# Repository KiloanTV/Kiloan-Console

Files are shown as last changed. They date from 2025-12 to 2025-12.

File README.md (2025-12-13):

<div>
  <h1 align="center">Kiloan Desk</h1>

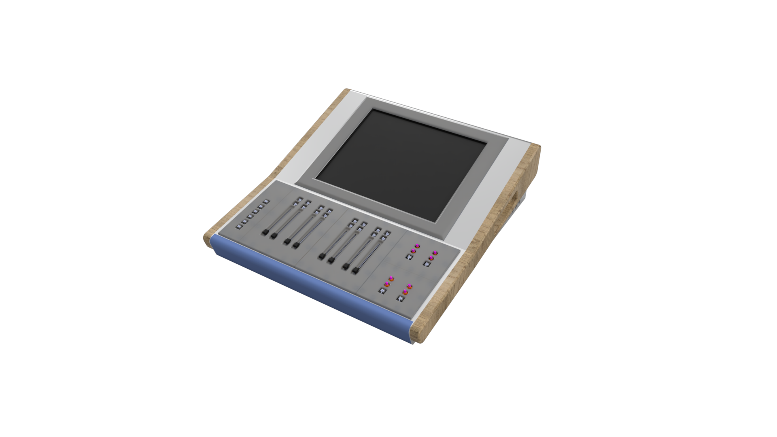
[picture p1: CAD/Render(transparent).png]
Kiloan-Desk
  

  <p align="center">
  <a href="https://blueprint.hackclub.com/">
    
  </a>
  </p>
  <h1></h1>
  <p align="center">
    A customizable mixing console like high quality chassis system for building your own console systems.
  </p>
</div>

<sub align="center">This work is licensed under the
[MIT License](https://mit-license.org).
</sub>

## Table of Contents

- [About](#about)
- [Pictures](#pictures)
- [Bill of Materials](#bill-of-materials)

# About

I have a dream: a self-designed system where everyone can build the perfect mixing console/video console/DIY whatever console out of Aluminum Sheet Metal and a bit of the best hoppyist in house fabrication, 3d printing! And that's why I did this project, it's adapted somewhat to my current wishes and needs, but it can be individually adapted and replicated by anyone without breaking the budget.

# Pictures

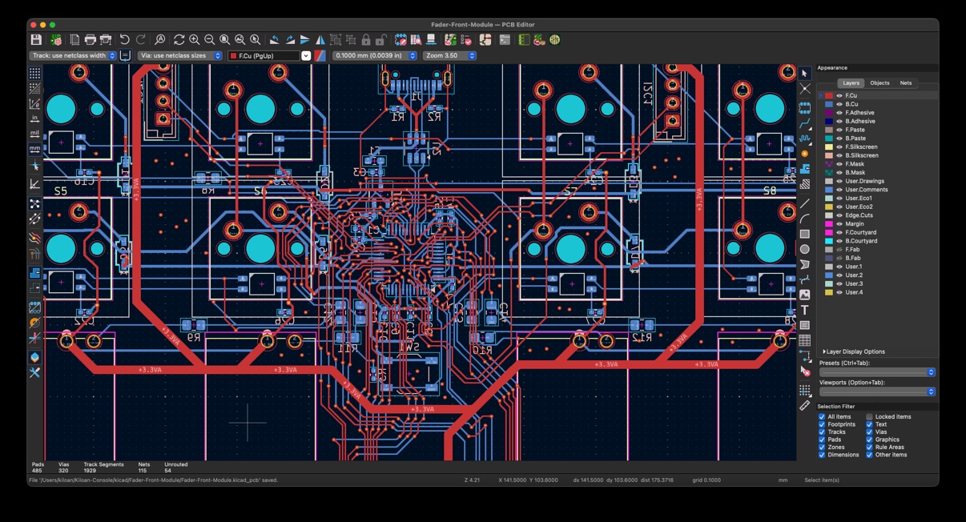
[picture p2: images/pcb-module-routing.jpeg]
pcb-routing


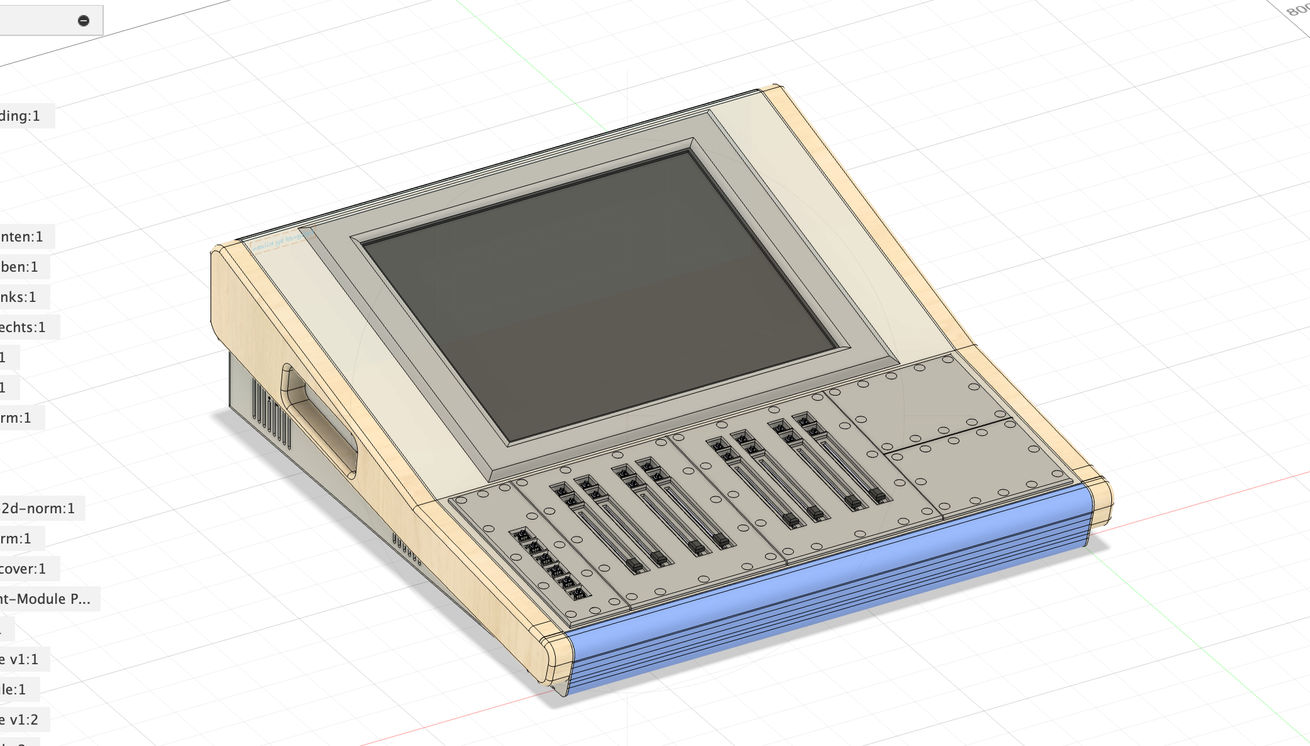
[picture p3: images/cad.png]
cad


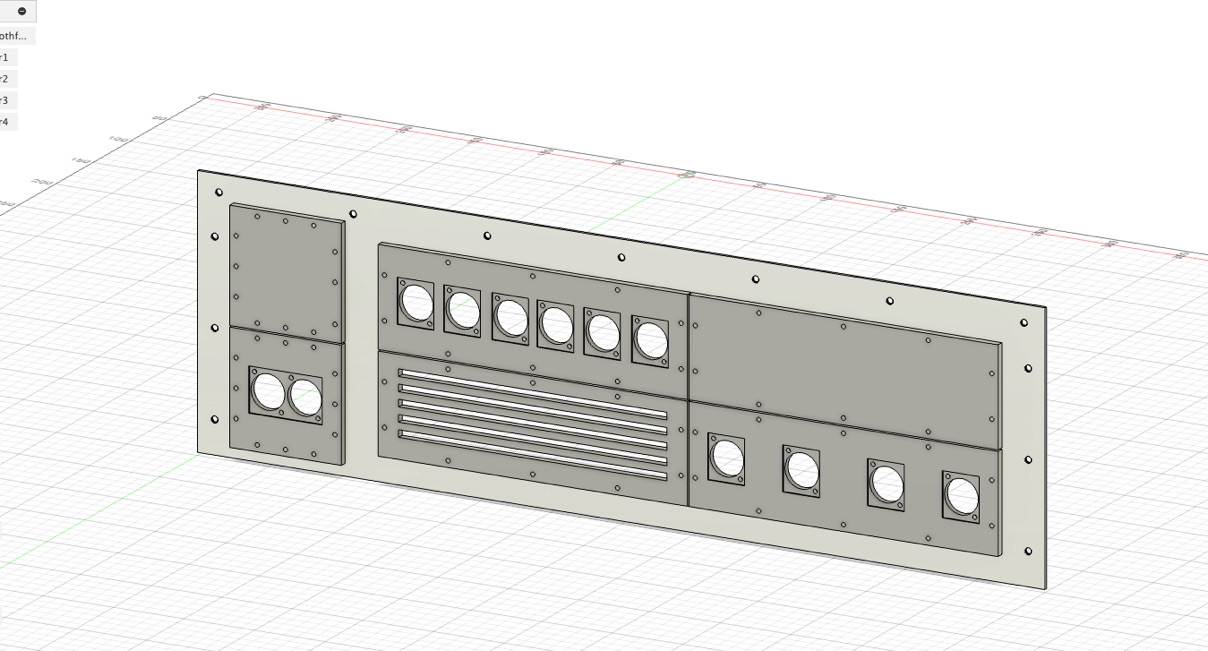
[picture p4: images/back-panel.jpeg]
backpanel


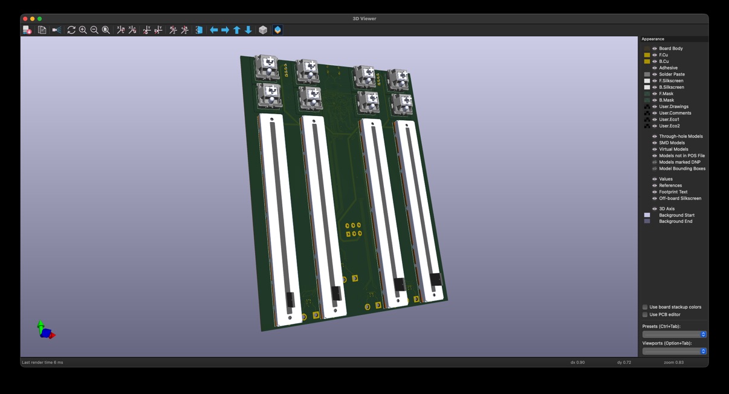
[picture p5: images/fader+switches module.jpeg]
pcb


# Bill of Materials

<details>
<summary><strong>Show Bill Of Materials(BOM) ----></strong></summary>

|Part Name |Quantity |Price |Vendor |Shipping Cost |Total Cost |Link(if applicable) |
|---|---|---|---|---|---|---|
|Misc Front Module PCBs + Stencil |1x5 |€9.35 |jlcpcb | | | |
|Fader Front Module PCBs + Stencil |1x5 |€16.58 |jlcpcb | | | |
|Deck Switcher Front Module PCBs + Stencil |1x5 |€10.71 |jlcpcb |Shipping for all 3 PCB orders: €47.18 | | |
|LCSC Electronic Components for 1x Deck Switcher/2x Fader/2x Misc|1 Order for everything(see lcsc cart export)|€87,81 |lcsc |€9,37 | | |
|Keyswitches for the PCBs |3x10pcs |€5,20 |aliexpress |€0 | |https://de.aliexpress.com/item/1005006814061416.html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|
|M5x10mm Screws |3x100pcs |€7,08 |schraubenking-shop.de(local and cheapest in my country)| | |https://www.schraubenking-shop.de/M5-x-10mm-Linsenkopfschrauben-TX-ISO14583-Edelstahl-A2-P004399 |
|M3x10mm Screws |1x100pcs |€1,98 |schraubenking-shop.de(local and cheapest in my country)|Shipping for everything from schraubenking: €5,84| |https://www.schraubenking-shop.de/M3-x-10mm-Linsenkopfschrauben-TX-ISO14583-Edelstahl-A2-P004381 |
|JLCCNC Sheet Metal Parts |10 individual parts |€146.97 |jlccnc |€78.28 | |jlccnc.com |
|Estimated Total | |€285,68 ($335,30)| |€140.67 ($165,15) |€426,35 ($500,56)| |

</details>

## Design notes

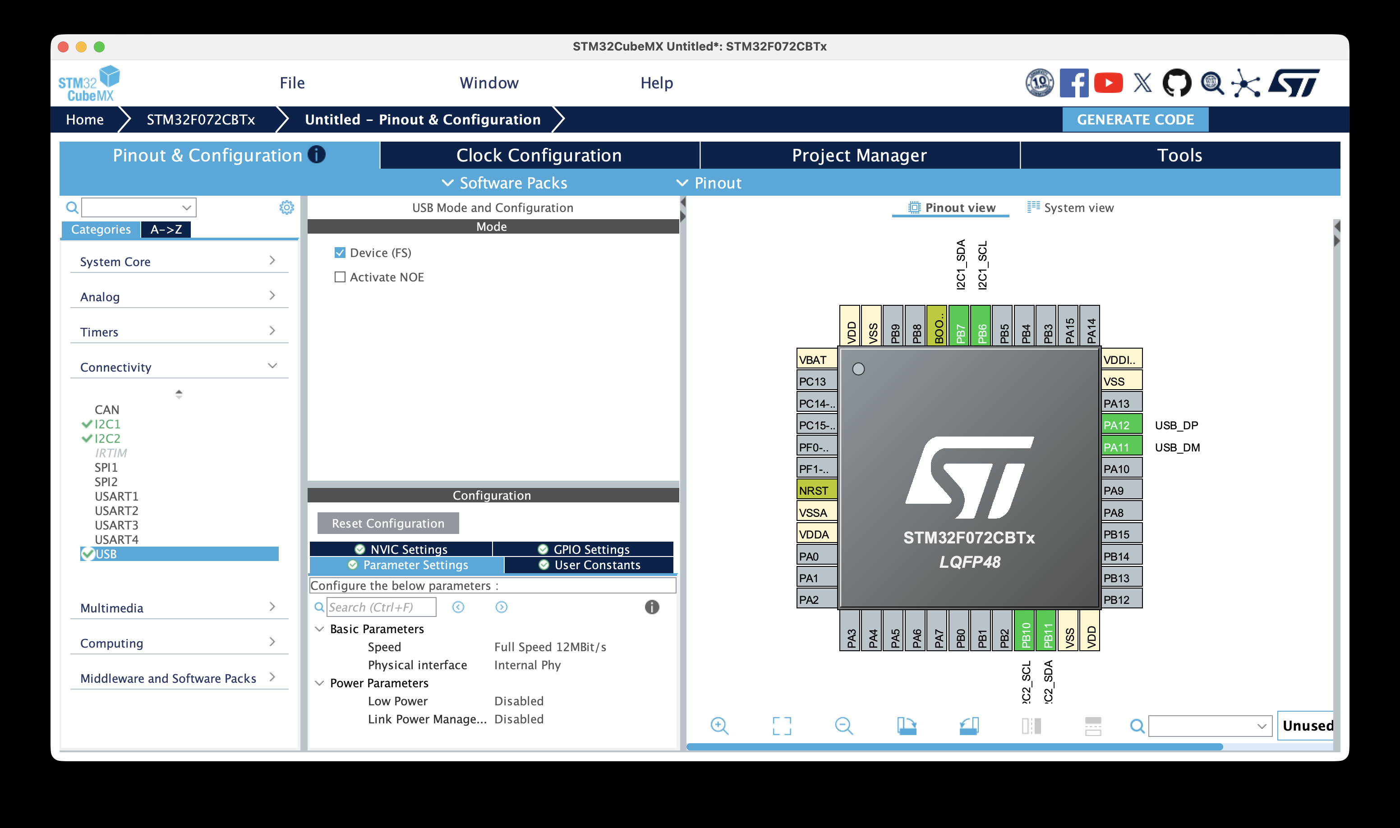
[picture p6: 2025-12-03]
firmware/General Pinout.png

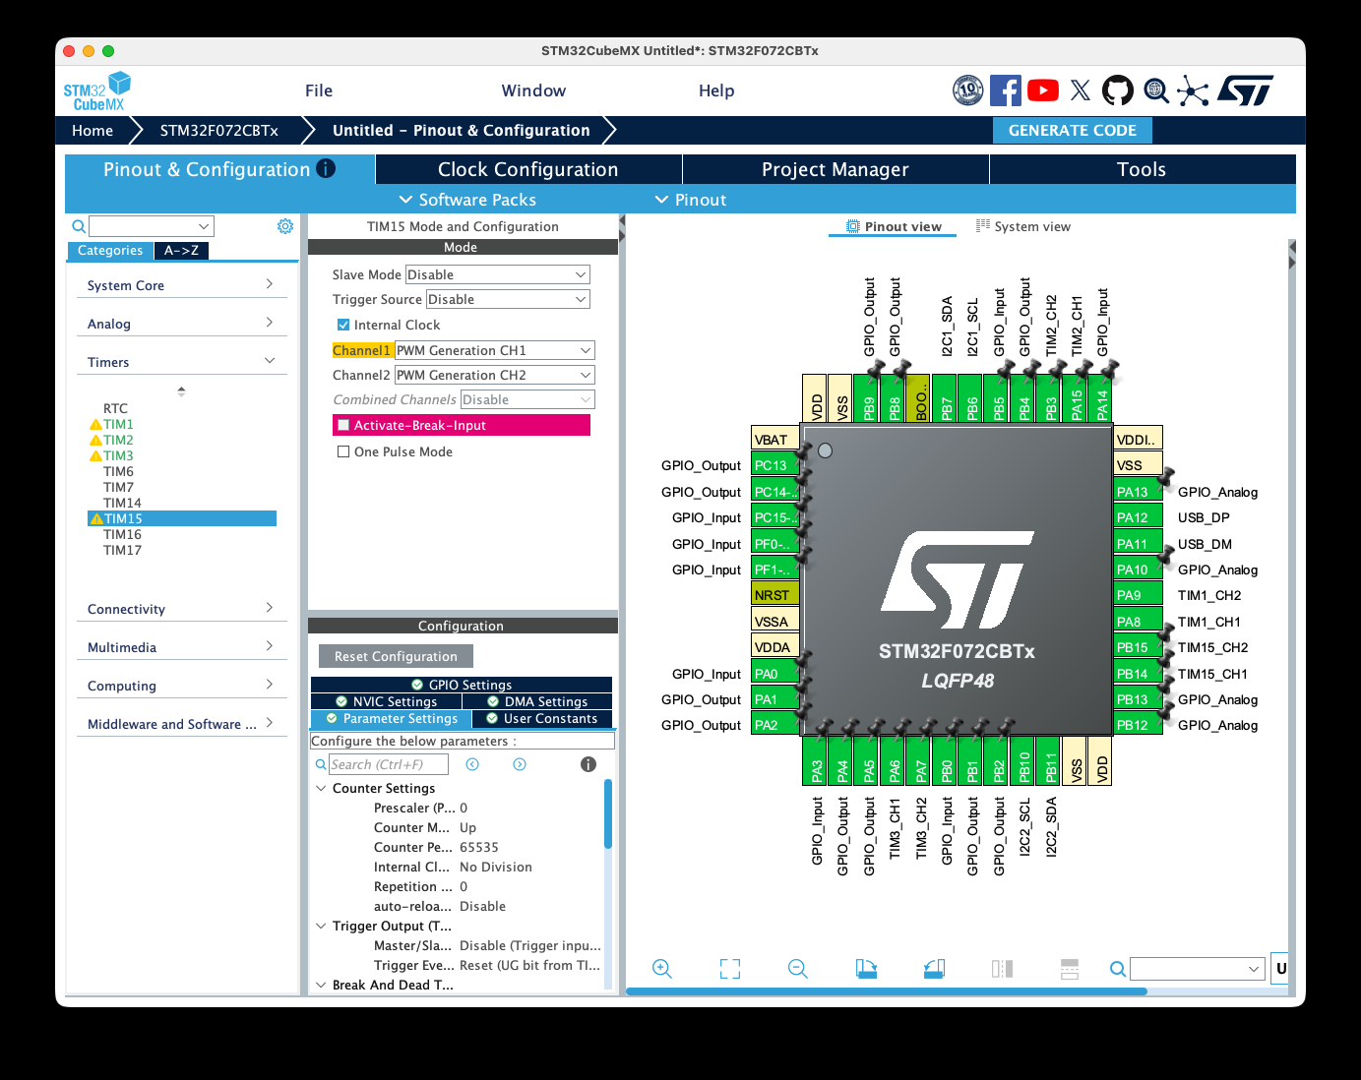
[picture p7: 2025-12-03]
firmware/Fader Module Pinout.png

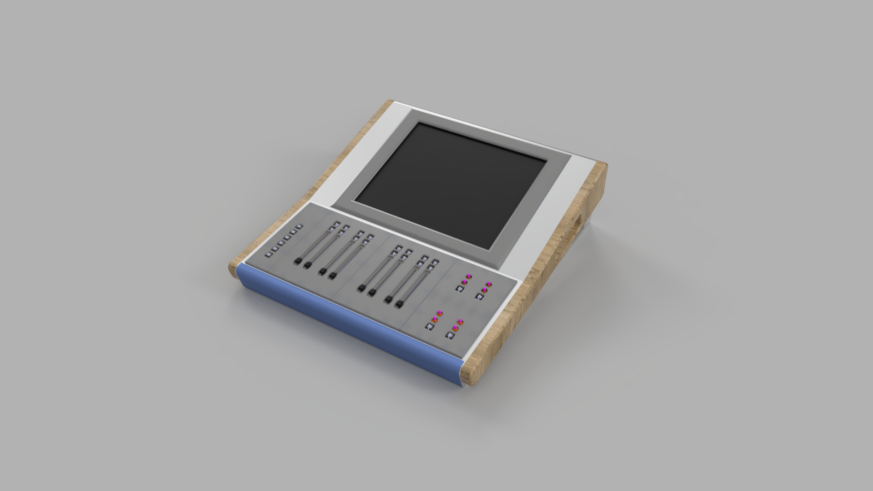
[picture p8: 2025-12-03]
CAD/Render.png

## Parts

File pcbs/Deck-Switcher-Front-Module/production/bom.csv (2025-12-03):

Designator | Footprint | Quantity | Value | LCSC Part #
C1, C11, C12, C13, C14, C15, C16, C17, C2, C5, C9 | 0402 | 11 | 100nF | C307331
C10, C6 | 0402 | 2 | 4.7uF | C23733
C3, C4, C8 | 0402 | 3 | 1uF | C52923
C7 | 0402 | 1 | 10nF | C15195
D1, D2, D3, D4, D5, D6 | SOD-123_ONS | 6 | Diode | C11177
F1 | 0603 | 1 | 500mA | C210357
J1 | USB_C_Receptacle_HRO_TYPE-C-31-M-12 | 1 | USB_C | C165948
J2, J3 | JST_EH_B4B-EH-A_1x04_P2.50mm_Vertical | 2 | I2C1 | C160258
J4 | SolderWire-2sqmm_1x02_P7.8mm_D2mm_OD3.9mm | 1 | External PowerSupply | C471417
LED1, LED2, LED3, LED4, LED5, LED6 | LED_SK6812MINI | 6 | LED_SK6812MINI | C5149201
R1, R2, R41, R42, R43, R44 | 0402 | 6 | 5.1k | C25905
R3 | 0402 | 1 | 10k | C25744
R4 | 0805 | 1 | 500Ω | C2828857
S1, S2, S3, S4, S5, S6 | MX_PCB_1.00u | 6 | Keyswitch
SW1 | SW_SPST_TL3342 | 1 | SW_Push | C115351
U1 | SOT-23-3 | 1 | XC6206 | C5446
U2 | SOT-23-6_Handsoldering | 1 | USBLC6-2SC6 | C2827654
U3 | LQFP-48_7x7mm_P0.5mm | 1 | STM32F072CBT6 | C81720

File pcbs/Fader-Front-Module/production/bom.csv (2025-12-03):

Designator | Footprint | Quantity | Value | LCSC Part #
C1, C11, C16, C2, C22, C23, C24, C25, C26, C27, C28, C5, C9 | 0402 | 13 | 100nF | C307331
C10, C6 | 0402 | 2 | 4.7uF | C23733
C12, C13, C14, C15 | 0805 | 4 | 1nF | C94121
C17, C21, C29, C30, C34, C35, C39, C40 | 0805 | 8 | 10uF | C15850
C18, C31, C36, C41 | 0805 | 4 | 1uF | C28323
C19, C32, C37, C42 | 0805 | 4 | 100nF | C49678
C20, C33, C38, C43 | 0805 | 4 | 10nF | C1710
C3, C4, C8 | 0402 | 3 | 1uF | C52923
C7 | 0402 | 1 | 10nF | C15195
D1, D2, D3, D4, D5, D6, D7, D8 | SOD-123_ONS | 8 | Diode | C11177
D10, D11, D12, D9 | LL-34 | 4 | Motor Diode | C2891753
F1 | 0603 | 1 | 500mA | C210357
J1 | USB_C_Receptacle_HRO_TYPE-C-31-M-12 | 1 | USB_C | C165948
J10, J12, J6, J8 | SolderWire-2sqmm_1x02_P7.8mm_D2mm_OD3.9mm | 4 | motor_port_1
J11, J5, J7, J9 | TRANS_TSM018NB03CR_RLG | 4 | MOSFET P-CH 40V 70A PDFN5x6-8L | C5297498
J2, J3 | JST_EH_B4B-EH-A_1x04_P2.50mm_Vertical | 2 | I2C1 | C160258
J4 | Molex_Mini-Fit_Jr_5566-06A_2x03_P4.20mm_Vertical | 1 | External PowerSupply | C471417
LED1, LED2, LED3, LED4, LED5, LED6, LED7, LED8 | LED_SK6812MINI | 8 | LED_SK6812MINI | C5149201
R1, R2, R41, R42, R43, R44 | 0402 | 6 | 5.1k | C25905
R10, R11, R12, R8, R9 | 0805 | 5 | 500Ω | C2828857
R13, R18, R20, R25, R27, R32, R34, R39 | 0805 | 8 | 22kΩ | C2907243
R14, R21, R28, R35 | 0805 | 4 | 1kΩ | C95781
R15, R16, R17, R19, R22, R23, R24, R26, R29, R30, R31, R33, R36, R37, R38, R40 | 0805 | 16 | 0Ω | DNP
R3 | 0402 | 1 | 10k | C25744
R4, R5, R6, R7 | schieberegler-PTB0153-2010BPB103 | 4 | PTB0153-2010BPB103 | C17427549
S1, S2, S3, S4, S5, S6, S7, S8 | MX_PCB_1.00u | 8 | Keyswitch
SW1 | SW_SPST_TL3342 | 1 | SW_Push | C115351
U1 | SOT-23-3 | 1 | XC6206 | C5446
U2 | SOT-23-6_Handsoldering | 1 | USBLC6-2SC6 | C2827654
U3 | LQFP-48_7x7mm_P0.5mm | 1 | STM32F072CBT6 | C81720
U4, U5, U6, U7 | RXY0014A-MFG | 4 | DRV8243HQRXYRQ1 | C3040833

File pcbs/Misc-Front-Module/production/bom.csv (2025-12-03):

Designator | Footprint | Quantity | Value | LCSC Part #
C1, C11, C12, C13, C14, C15, C16, C17, C18, C19, C2, C5, C9 | 0402 | 13 | 100nF | C307331
C10, C6 | 0402 | 2 | 4.7uF | C23733
C3, C4, C8 | 0402 | 3 | 1uF | C52923
C7 | 0402 | 1 | 10nF | C15195
D1, D2 | SOD-123_ONS | 2 | Diode | C11177
F1 | 0603 | 1 | 500mA | C210357
J1 | USB_C_Receptacle_HRO_TYPE-C-31-M-12 | 1 | USB_C | C165948
J2, J3 | JST_EH_B4B-EH-A_1x04_P2.50mm_Vertical | 2 | I2C1 | C160258
J4 | SolderWire-2sqmm_1x02_P7.8mm_D2mm_OD3.9mm | 1 | External PowerSupply | C471417
R1, R2, R4, R5, R6, R7 | 0402 | 6 | 5.1k | C25905
R10, R11, R12, R13, R14, R15, R3, R8, R9 | 0402 | 9 | 10k | C25744
S1, S2 | MX_PCB_1.00u | 2 | Keyswitch
SW1 | SW_SPST_TL3342 | 1 | SW_Push | C115351
U1 | SOT-23-3 | 1 | XC6206 | C5446
U2 | SOT-23-6_Handsoldering | 1 | USBLC6-2SC6 | C2827654
U3 | LQFP-48_7x7mm_P0.5mm | 1 | STM32F072CBT6 | C81720
U4, U5, U6, U7 | EC12D1524403 | 4 | encoder EC12D1524403 | C112349

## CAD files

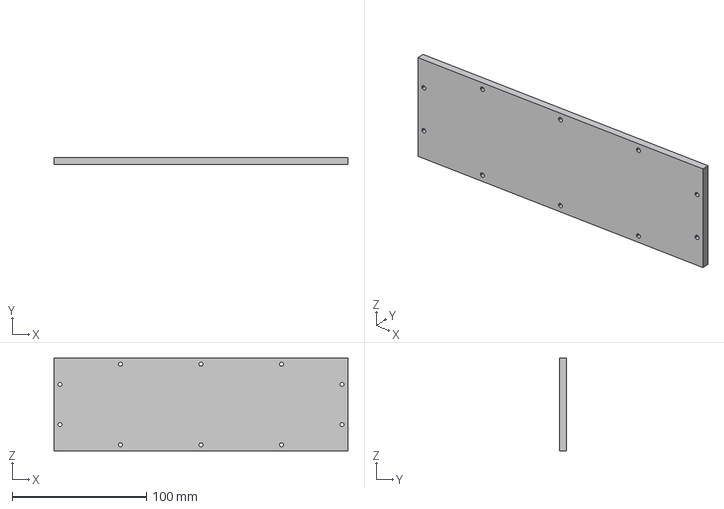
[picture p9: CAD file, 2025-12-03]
CAD/3D Printed/Back Modules/Big.step
219.0 x 5.00 x 69.0 mm

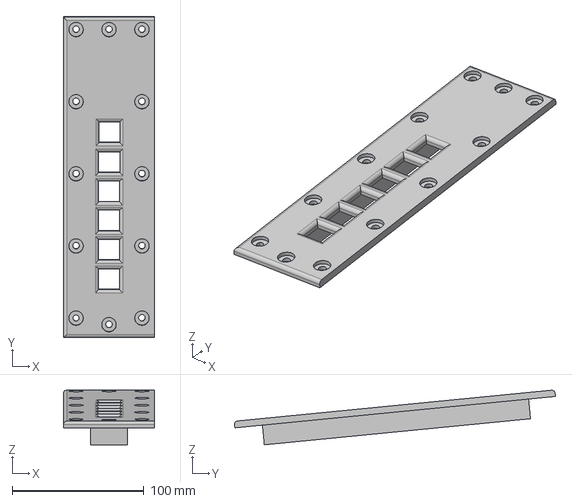
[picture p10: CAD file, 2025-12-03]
CAD/3D Printed/Front Modules/Desk-Switcher/Desk-Switcher-up.step
69.0 x 243.6 x 41.5 mm

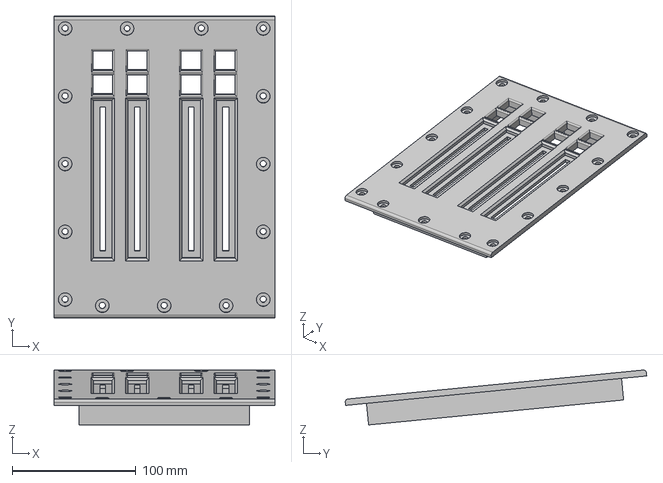
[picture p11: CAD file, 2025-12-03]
CAD/3D Printed/Front Modules/Fader-Module/Fader-Module-up.step
178.5 x 243.6 x 44.3 mm

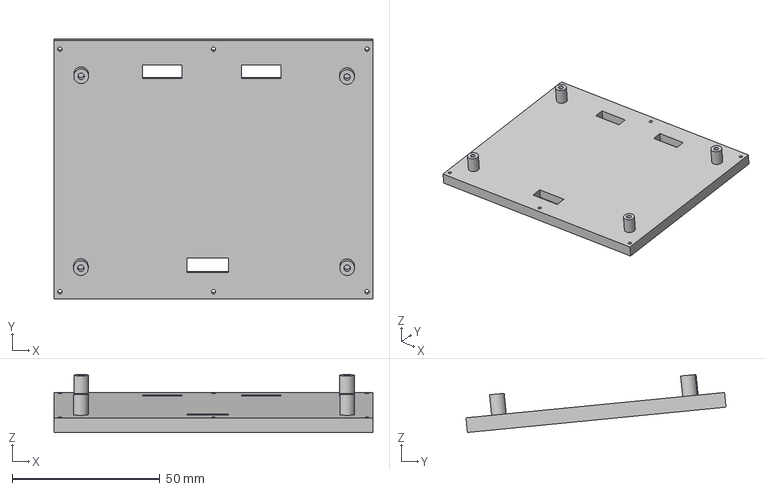
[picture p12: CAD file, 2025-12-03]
CAD/3D Printed/Front Modules/Misc-down/Misc-Down-down.step
108.0 x 88.1 x 19.6 mm

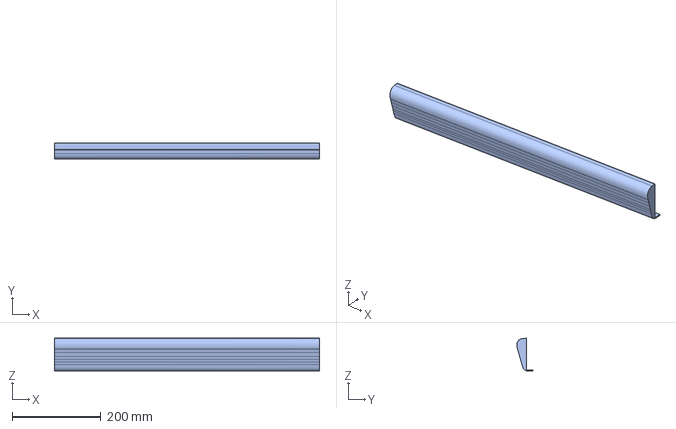
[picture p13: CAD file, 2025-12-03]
CAD/3D Printed/Front-Rounding.step
596.0 x 36.7 x 73.5 mm

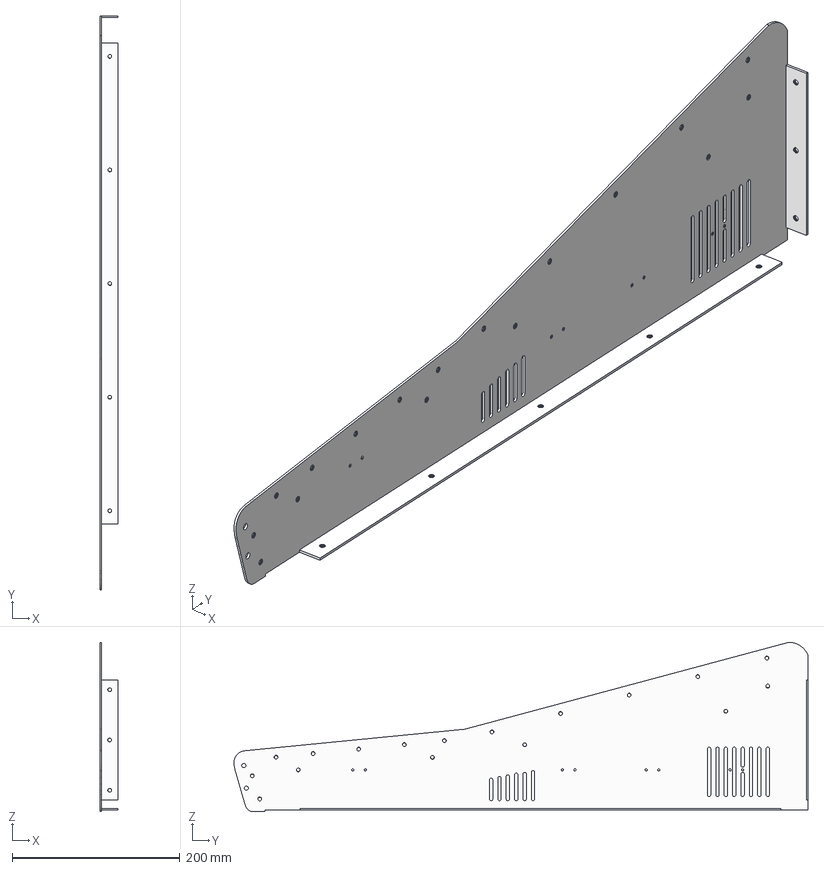
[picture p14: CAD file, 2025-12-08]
CAD/Sheet Metal (2mm Alu)/Left.step
22.0 x 684.7 x 202.0 mm

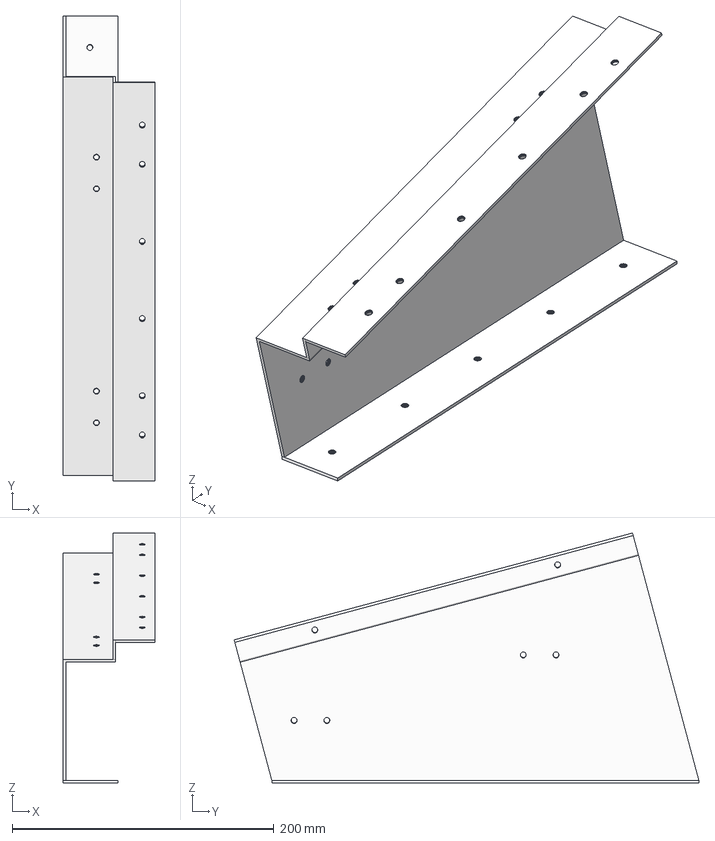
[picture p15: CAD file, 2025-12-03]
CAD/Sheet Metal (2mm Alu)/Screen-Mount/Screen-right.step
70.0 x 354.9 x 190.9 mm

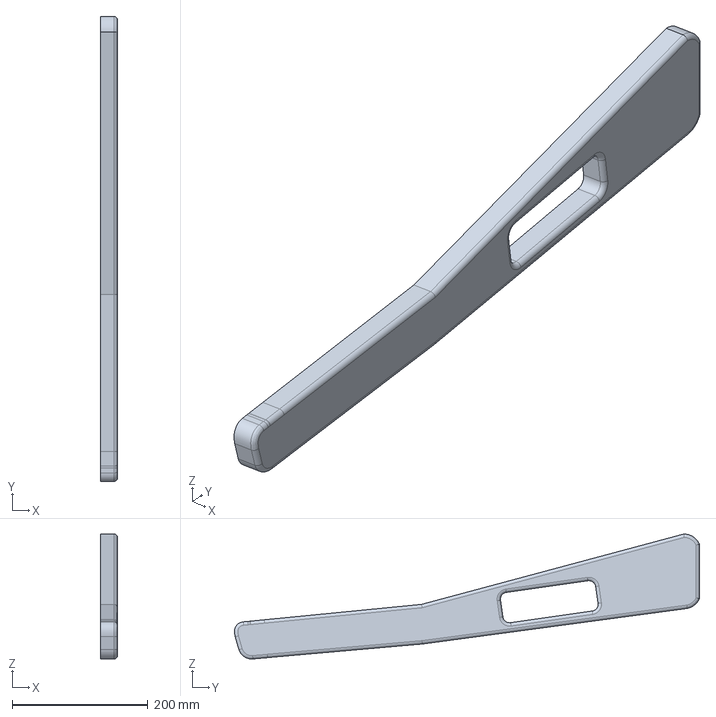
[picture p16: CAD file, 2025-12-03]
CAD/Wooden Parts/Extend-right.step
25.0 x 684.7 x 184.1 mm

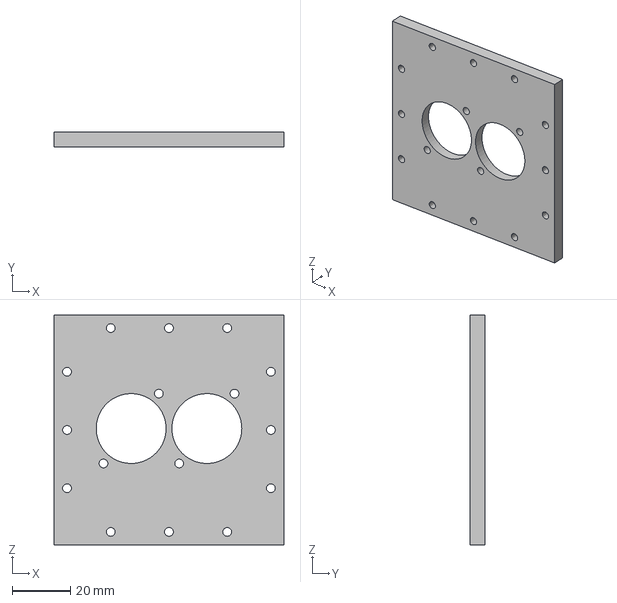
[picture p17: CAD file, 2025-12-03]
CAD/3D Printed/Back Modules/Small-2dnorm.step
79.0 x 5.00 x 79.0 mm

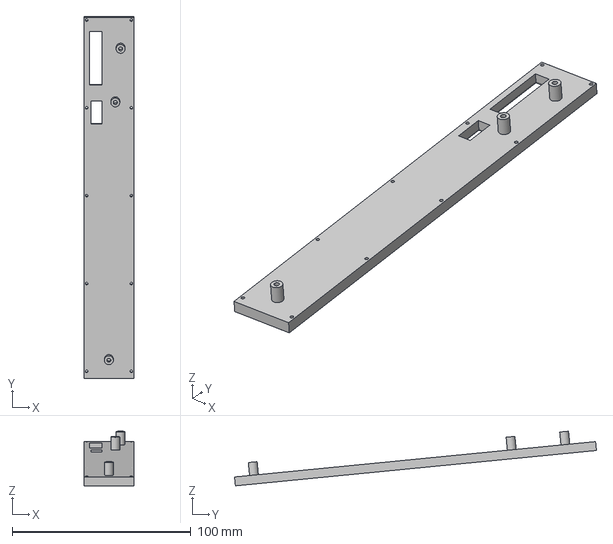
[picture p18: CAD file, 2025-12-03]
CAD/3D Printed/Front Modules/Desk-Switcher/Desk-Switcher-down.step
28.0 x 202.5 x 30.6 mm

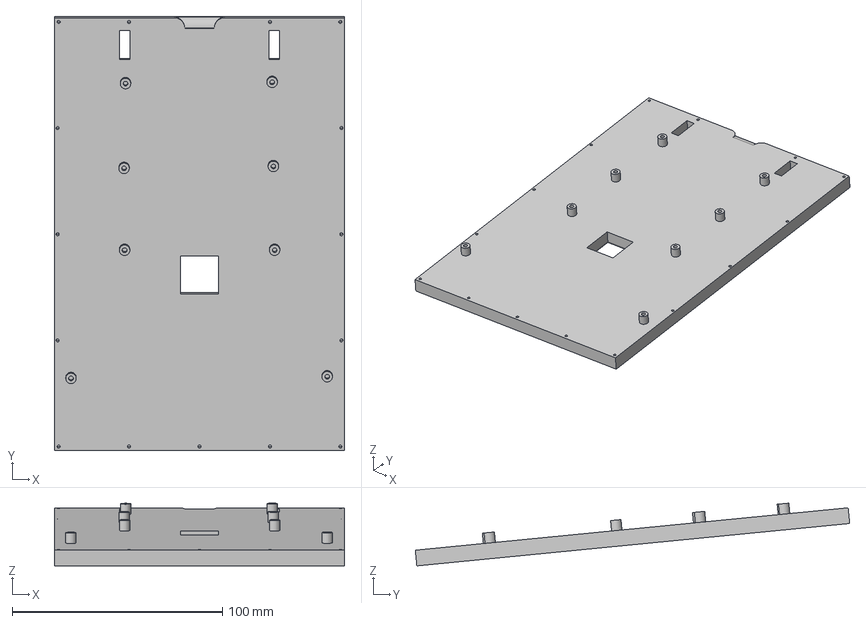
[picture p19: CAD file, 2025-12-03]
CAD/3D Printed/Front Modules/Fader-Module/Fader-Module-down.step
138.0 x 206.7 x 29.9 mm

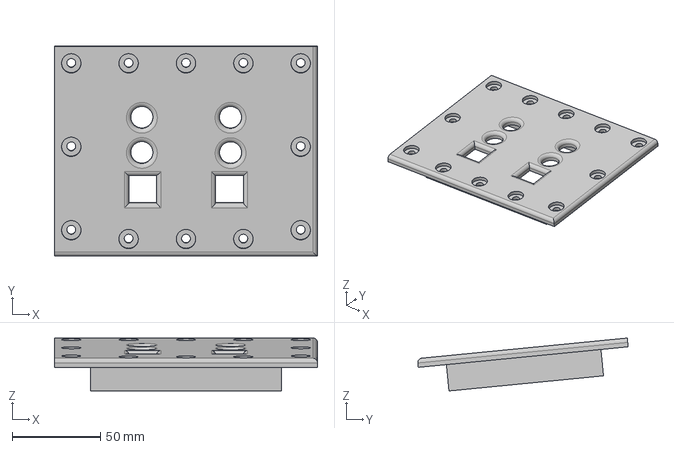
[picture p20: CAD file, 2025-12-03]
CAD/3D Printed/Front Modules/Misc-down/Misc-Down-up.step
149.0 x 119.2 x 30.0 mm

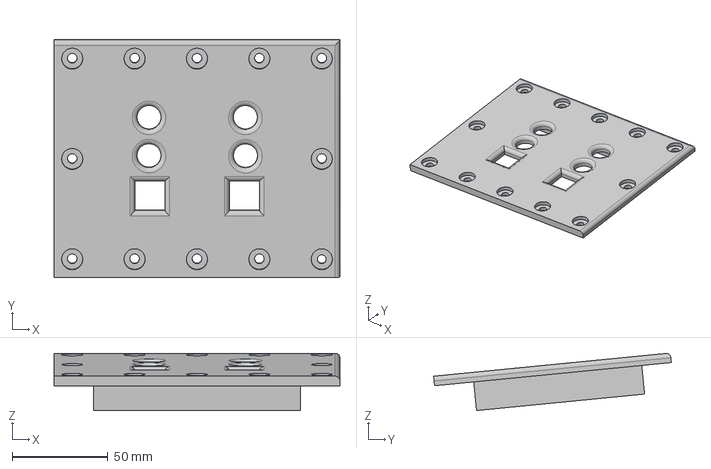
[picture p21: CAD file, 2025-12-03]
CAD/3D Printed/Front Modules/Misc-up/Misc-Up-up.step
149.0 x 123.9 x 29.8 mm

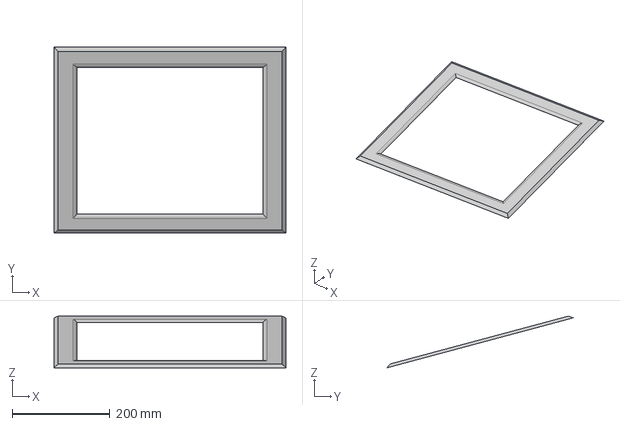
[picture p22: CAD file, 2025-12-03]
CAD/3D Printed/Screen-Cover.step
474.0 x 380.6 x 105.7 mm

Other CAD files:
CAD/3D Printed/Front Modules/Misc-up/Misc-up-down.step
CAD/Sheet Metal (2mm Alu)/Base.step
CAD/Sheet Metal (2mm Alu)/Screen-Mount/Screen-left.step
CAD/Wooden Parts/Extend-left.step
CAD/3D Printed/Back Modules/Big-4dnorm.step
CAD/3D Printed/Back Modules/Big-6dnorm.step
CAD/3D Printed/Back Modules/Big-air.step
CAD/3D Printed/Back Modules/Small.step
CAD/3D Printed/Front Modules/Screw-Covers.step
CAD/Sheet Metal (2mm Alu)/Right.step
CAD/Sheet Metal (2mm Alu)/Screen-Mount/Screen-Down.step
CAD/Sheet Metal (2mm Alu)/Screen-Mount/Screen-up.step
CAD/Sheet Metal (2mm Alu)/made-by-marking.dxf

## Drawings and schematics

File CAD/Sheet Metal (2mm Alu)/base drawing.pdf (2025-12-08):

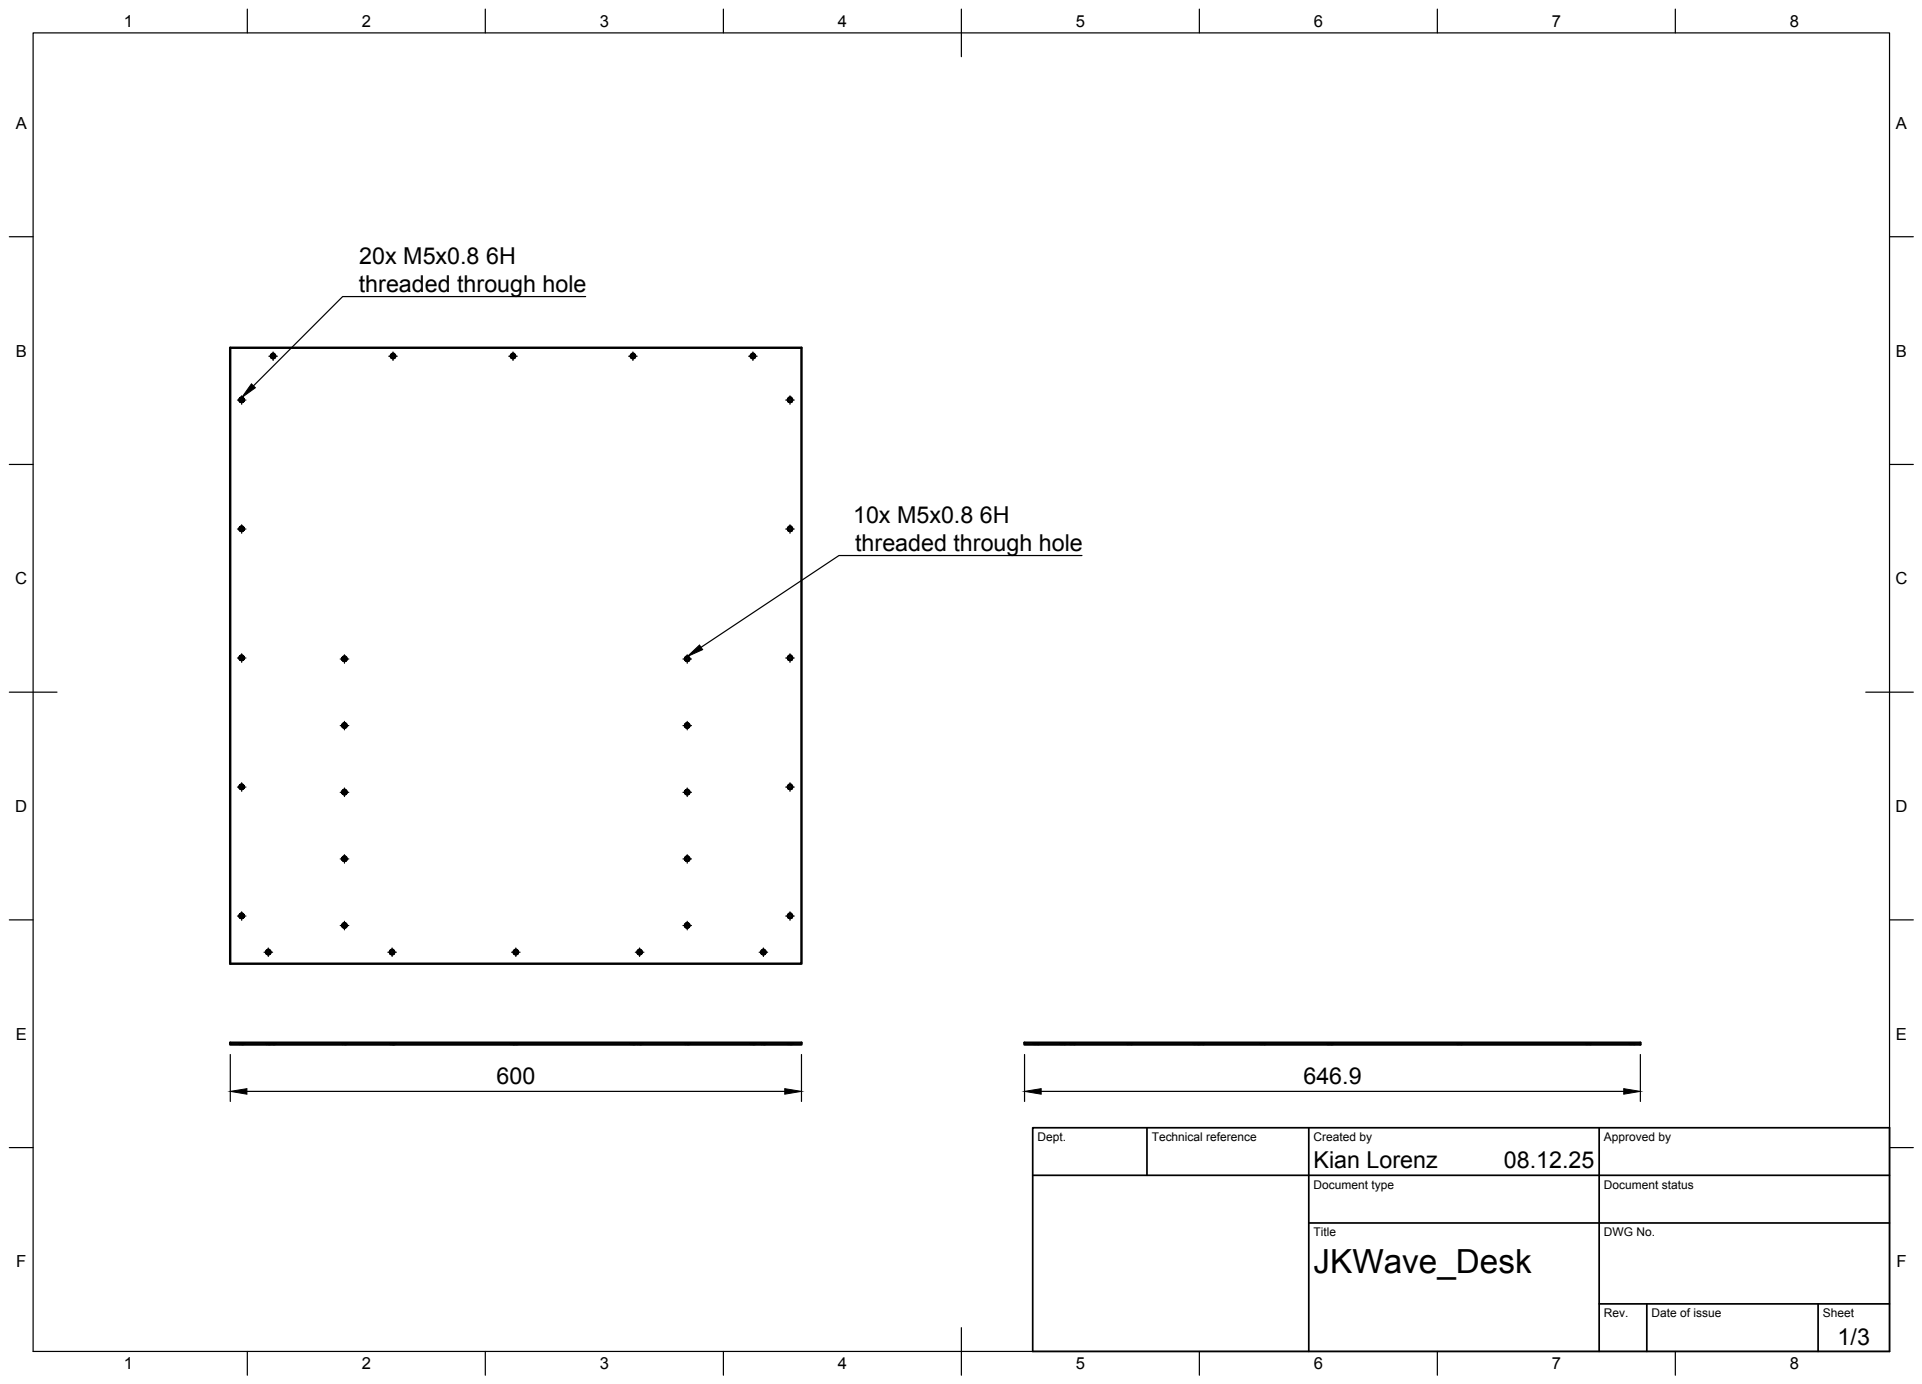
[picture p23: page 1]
Title; DWG No.; Rev.; Date of issue; Sheet

threaded through hole

Dept. | Technical reference | Created by Kian Lorenz 08.12.25 | Approved by

Document type | Document status

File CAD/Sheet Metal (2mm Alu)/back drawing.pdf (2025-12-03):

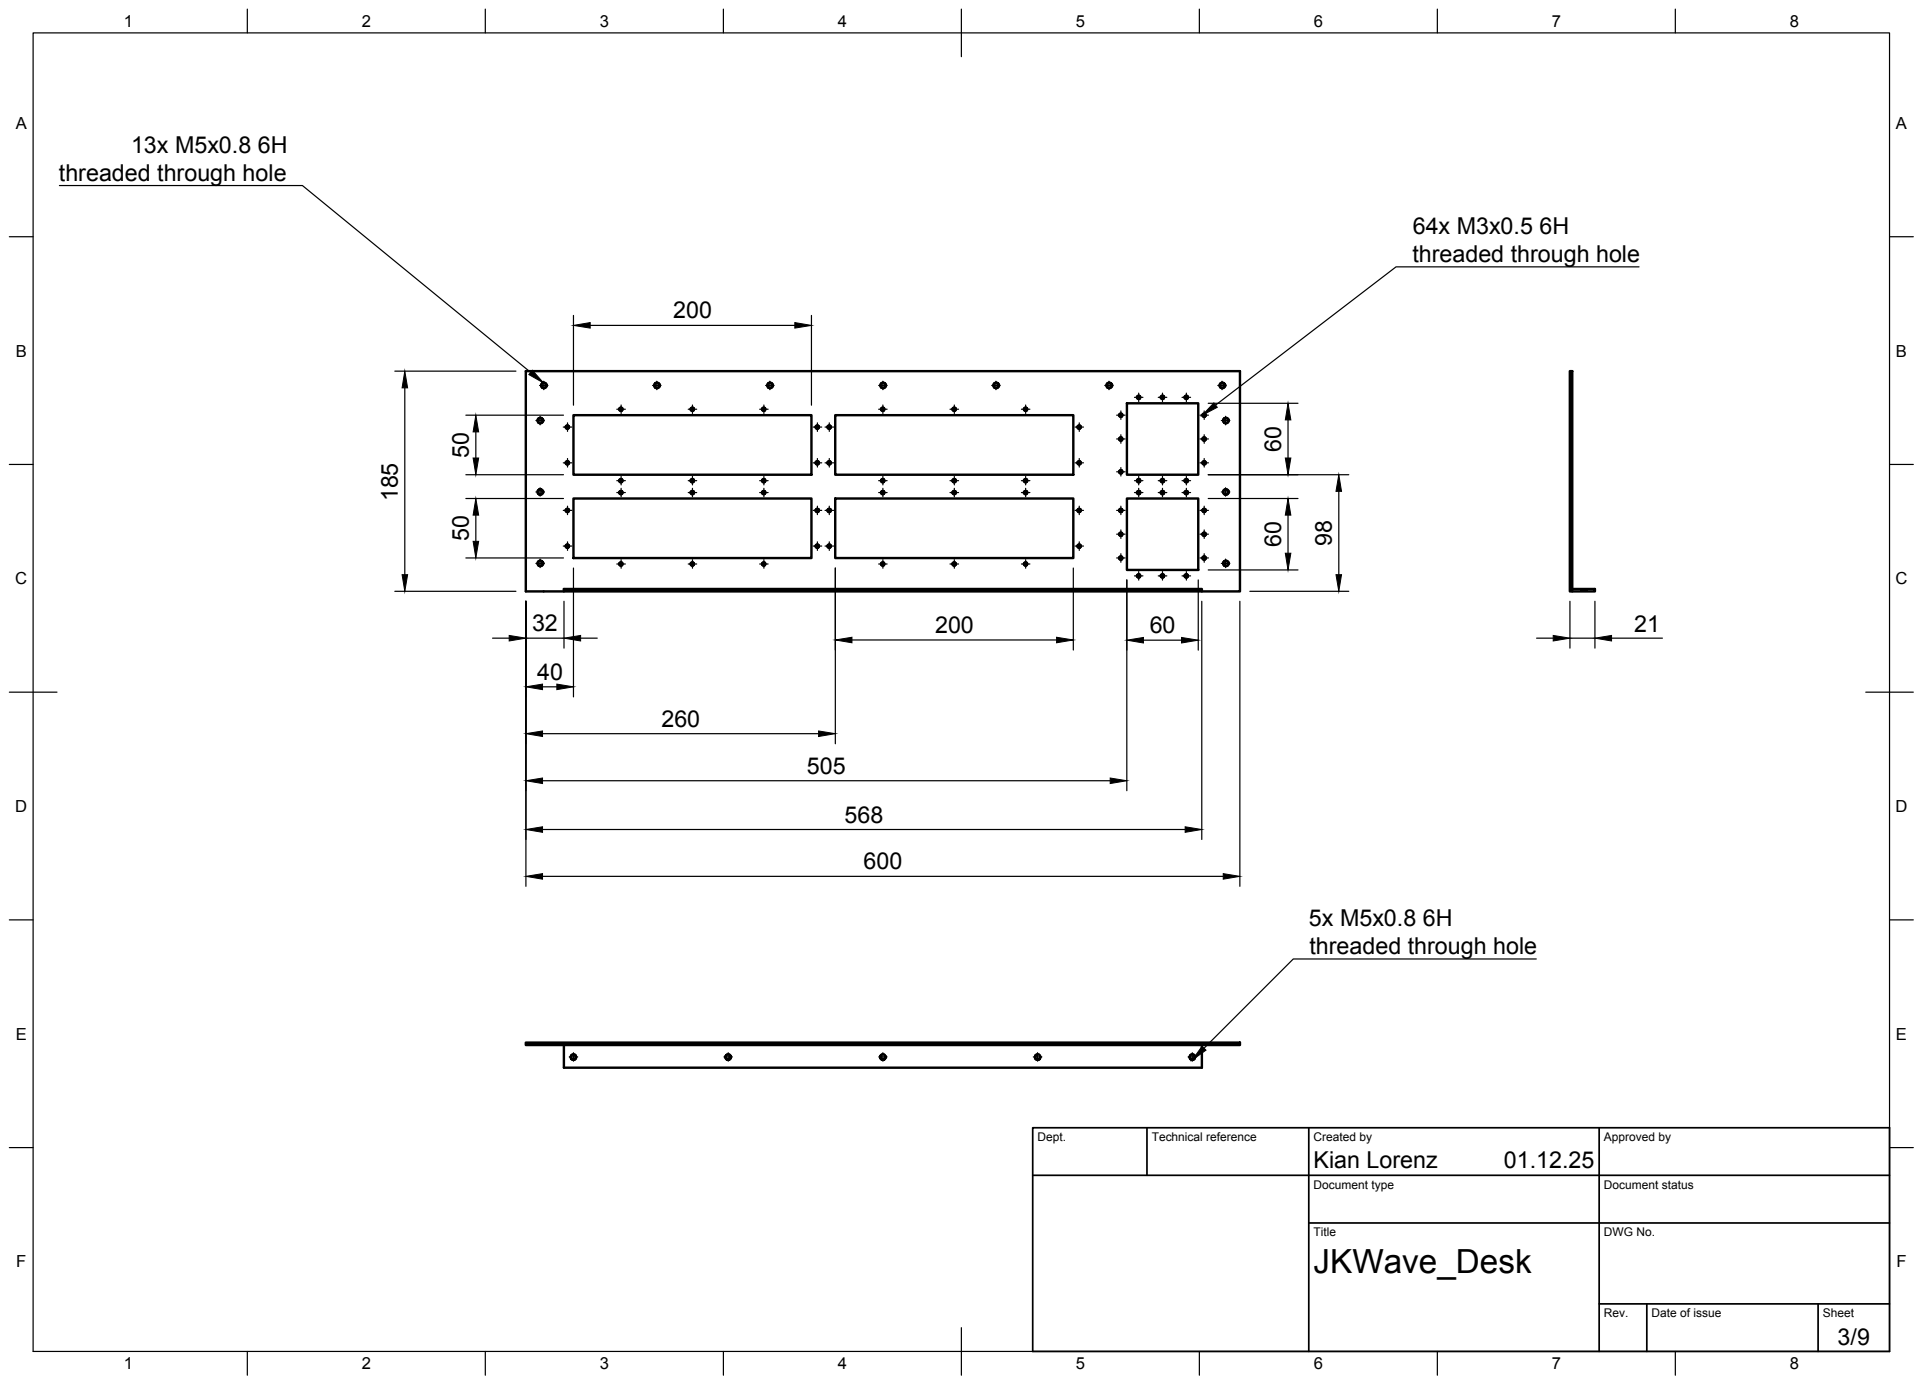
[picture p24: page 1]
Title; DWG No.; Rev.; Date of issue; Sheet

threaded through hole

Dept. | Technical reference | Created by Kian Lorenz 01.12.25 | Approved by

Document type | Document status

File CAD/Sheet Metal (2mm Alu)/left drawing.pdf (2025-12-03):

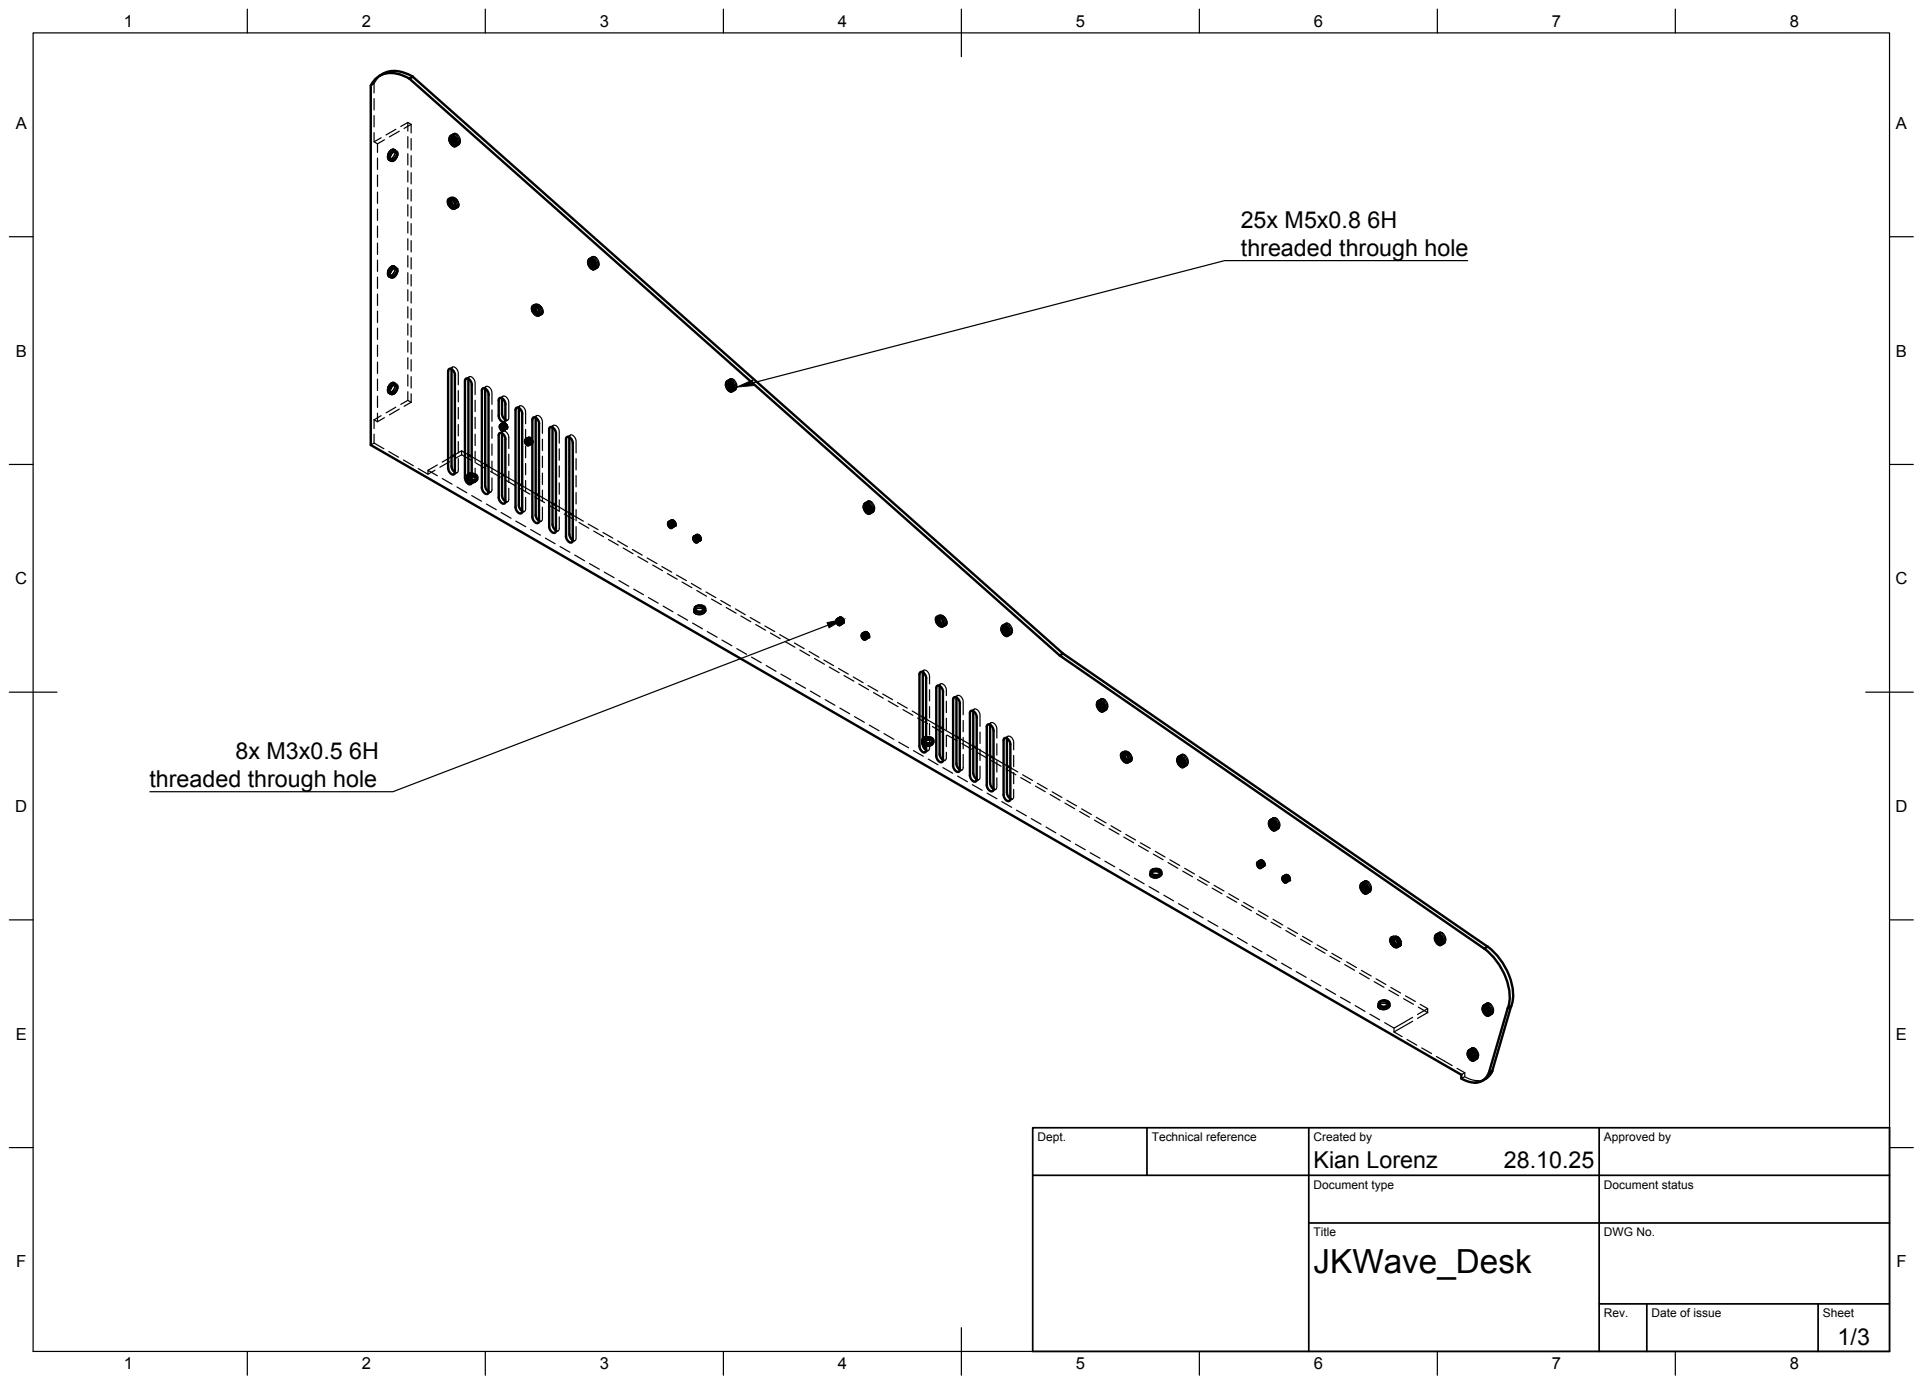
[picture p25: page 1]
Title; DWG No.; Rev.; Date of issue; Sheet

threaded through hole

Dept. | Technical reference | Created by Kian Lorenz 28.10.25 | Approved by

Document type | Document status

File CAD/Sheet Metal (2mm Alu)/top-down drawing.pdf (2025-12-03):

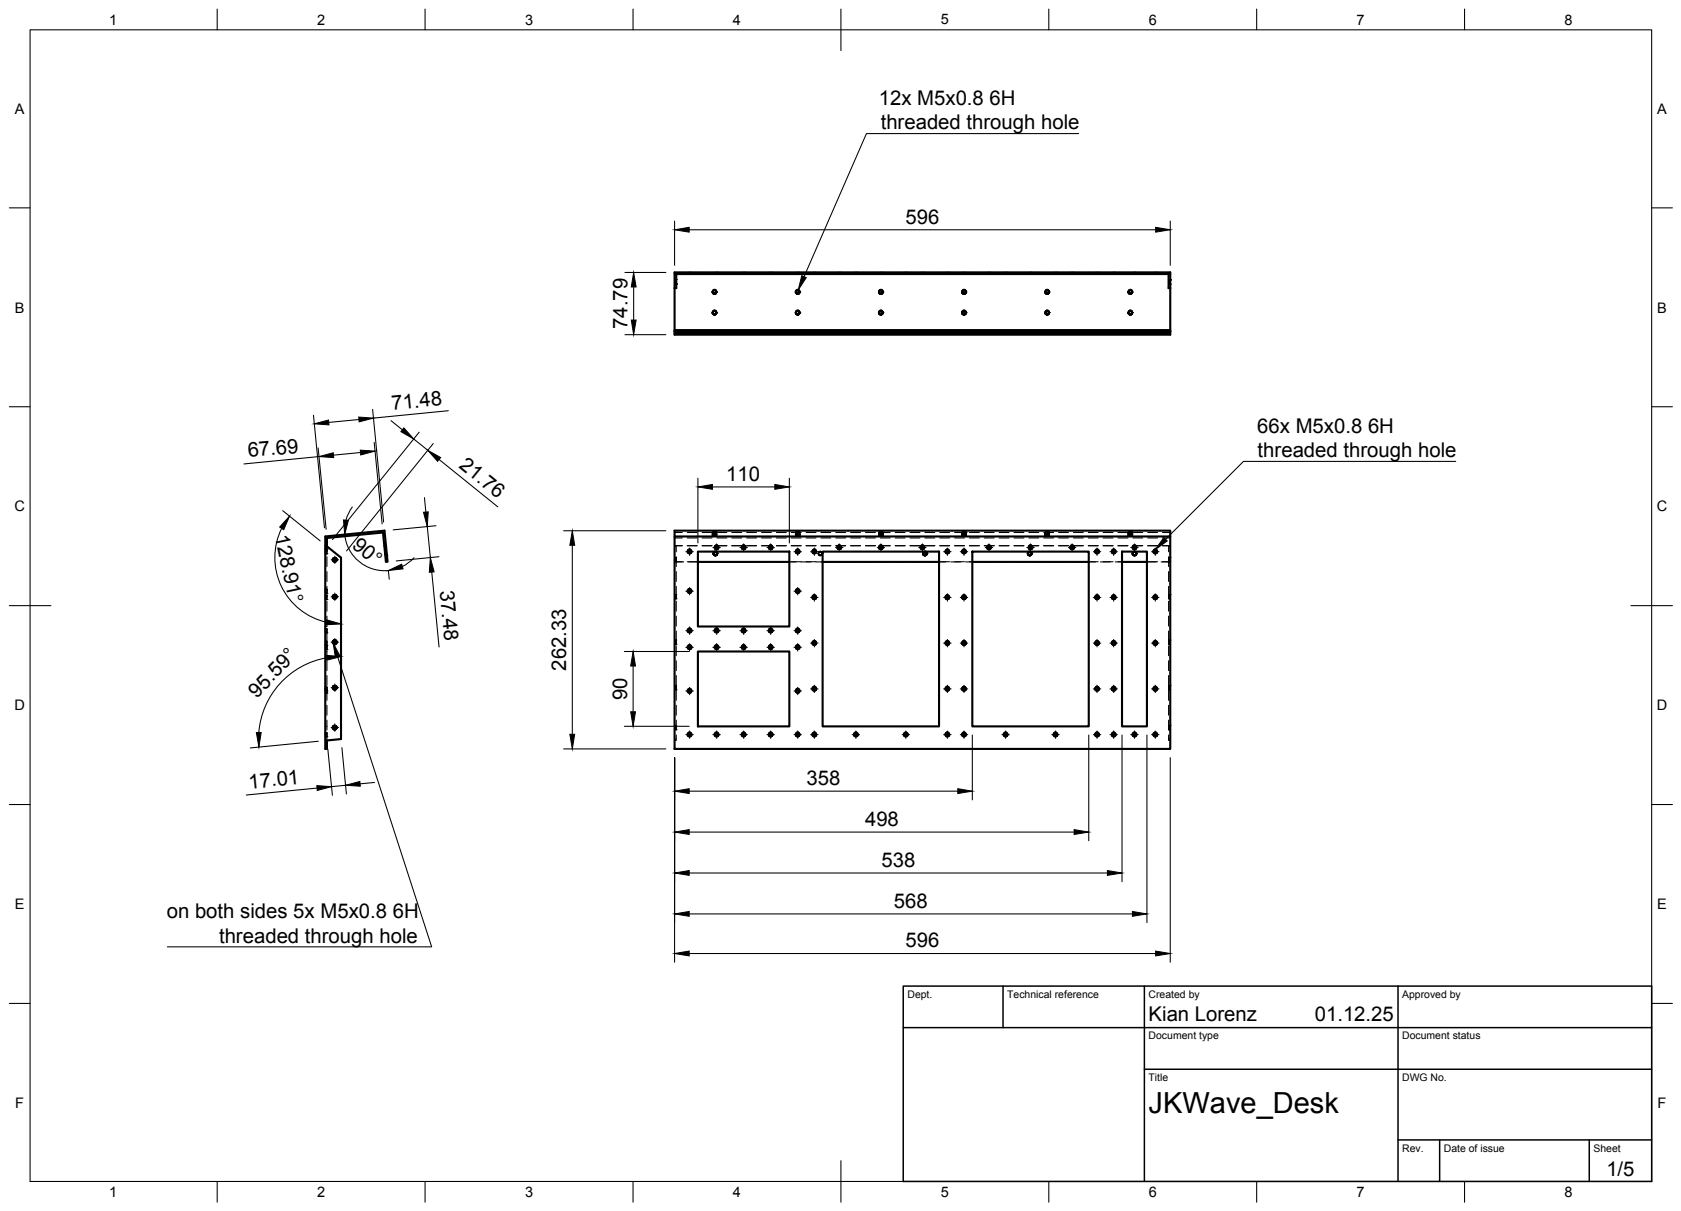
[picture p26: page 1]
Title; DWG No.; Rev.; Date of issue; Sheet

threaded through hole

on both sides 5x M5x0.8 6H

Dept. | Technical reference | Created by Kian Lorenz 01.12.25 | Approved by

Document type | Document status

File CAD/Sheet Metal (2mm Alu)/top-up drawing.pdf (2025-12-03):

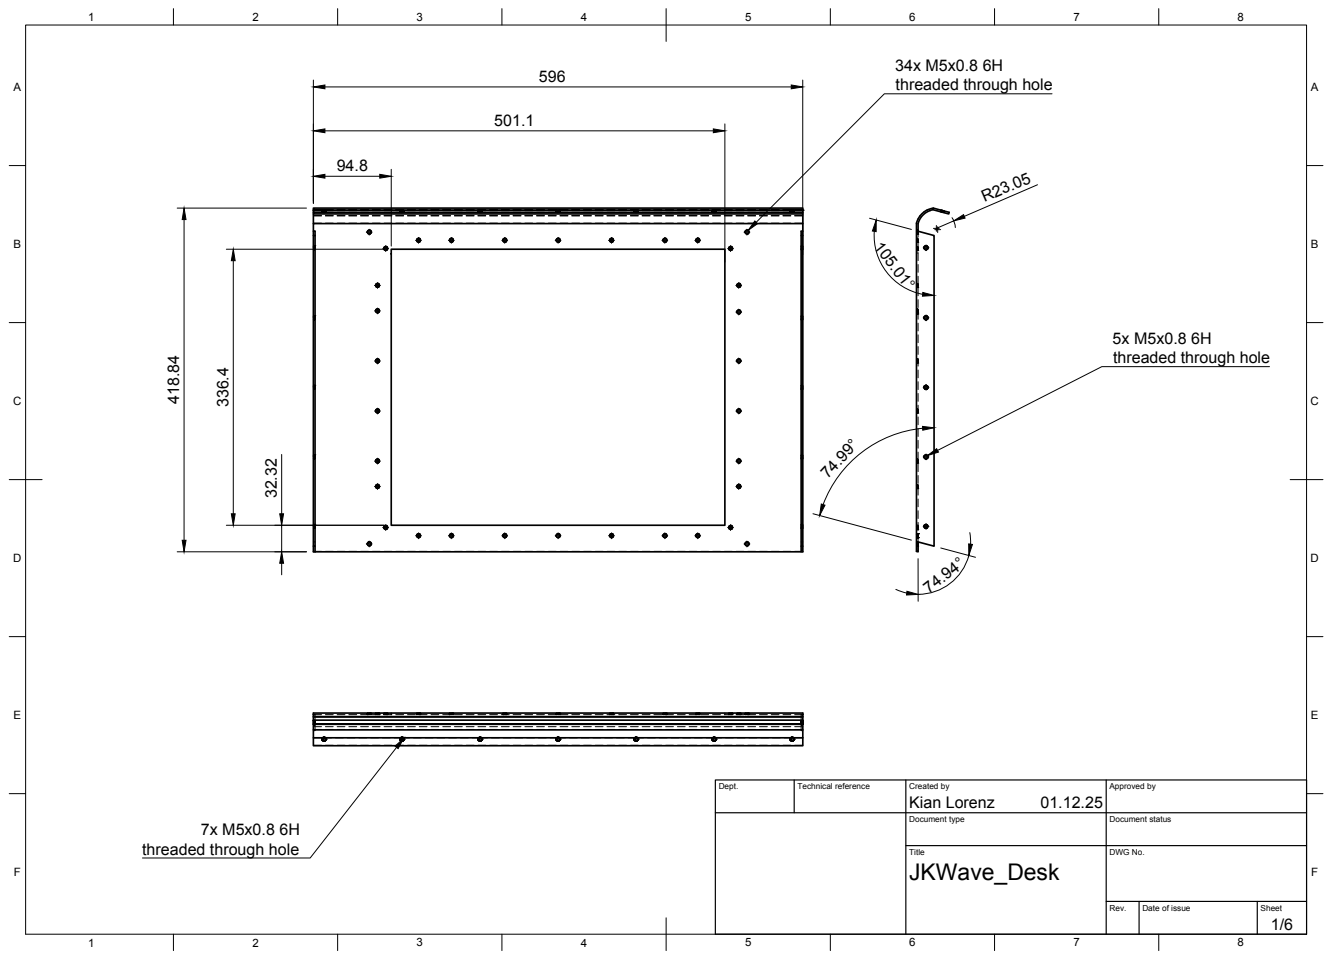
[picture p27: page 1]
Title; DWG No.; Rev.; Date of issue; Sheet; Kian Lorenz 418.84

threaded through hole

Dept. | Technical reference | Created by 01.12.25 | Approved by

Document type | Document status

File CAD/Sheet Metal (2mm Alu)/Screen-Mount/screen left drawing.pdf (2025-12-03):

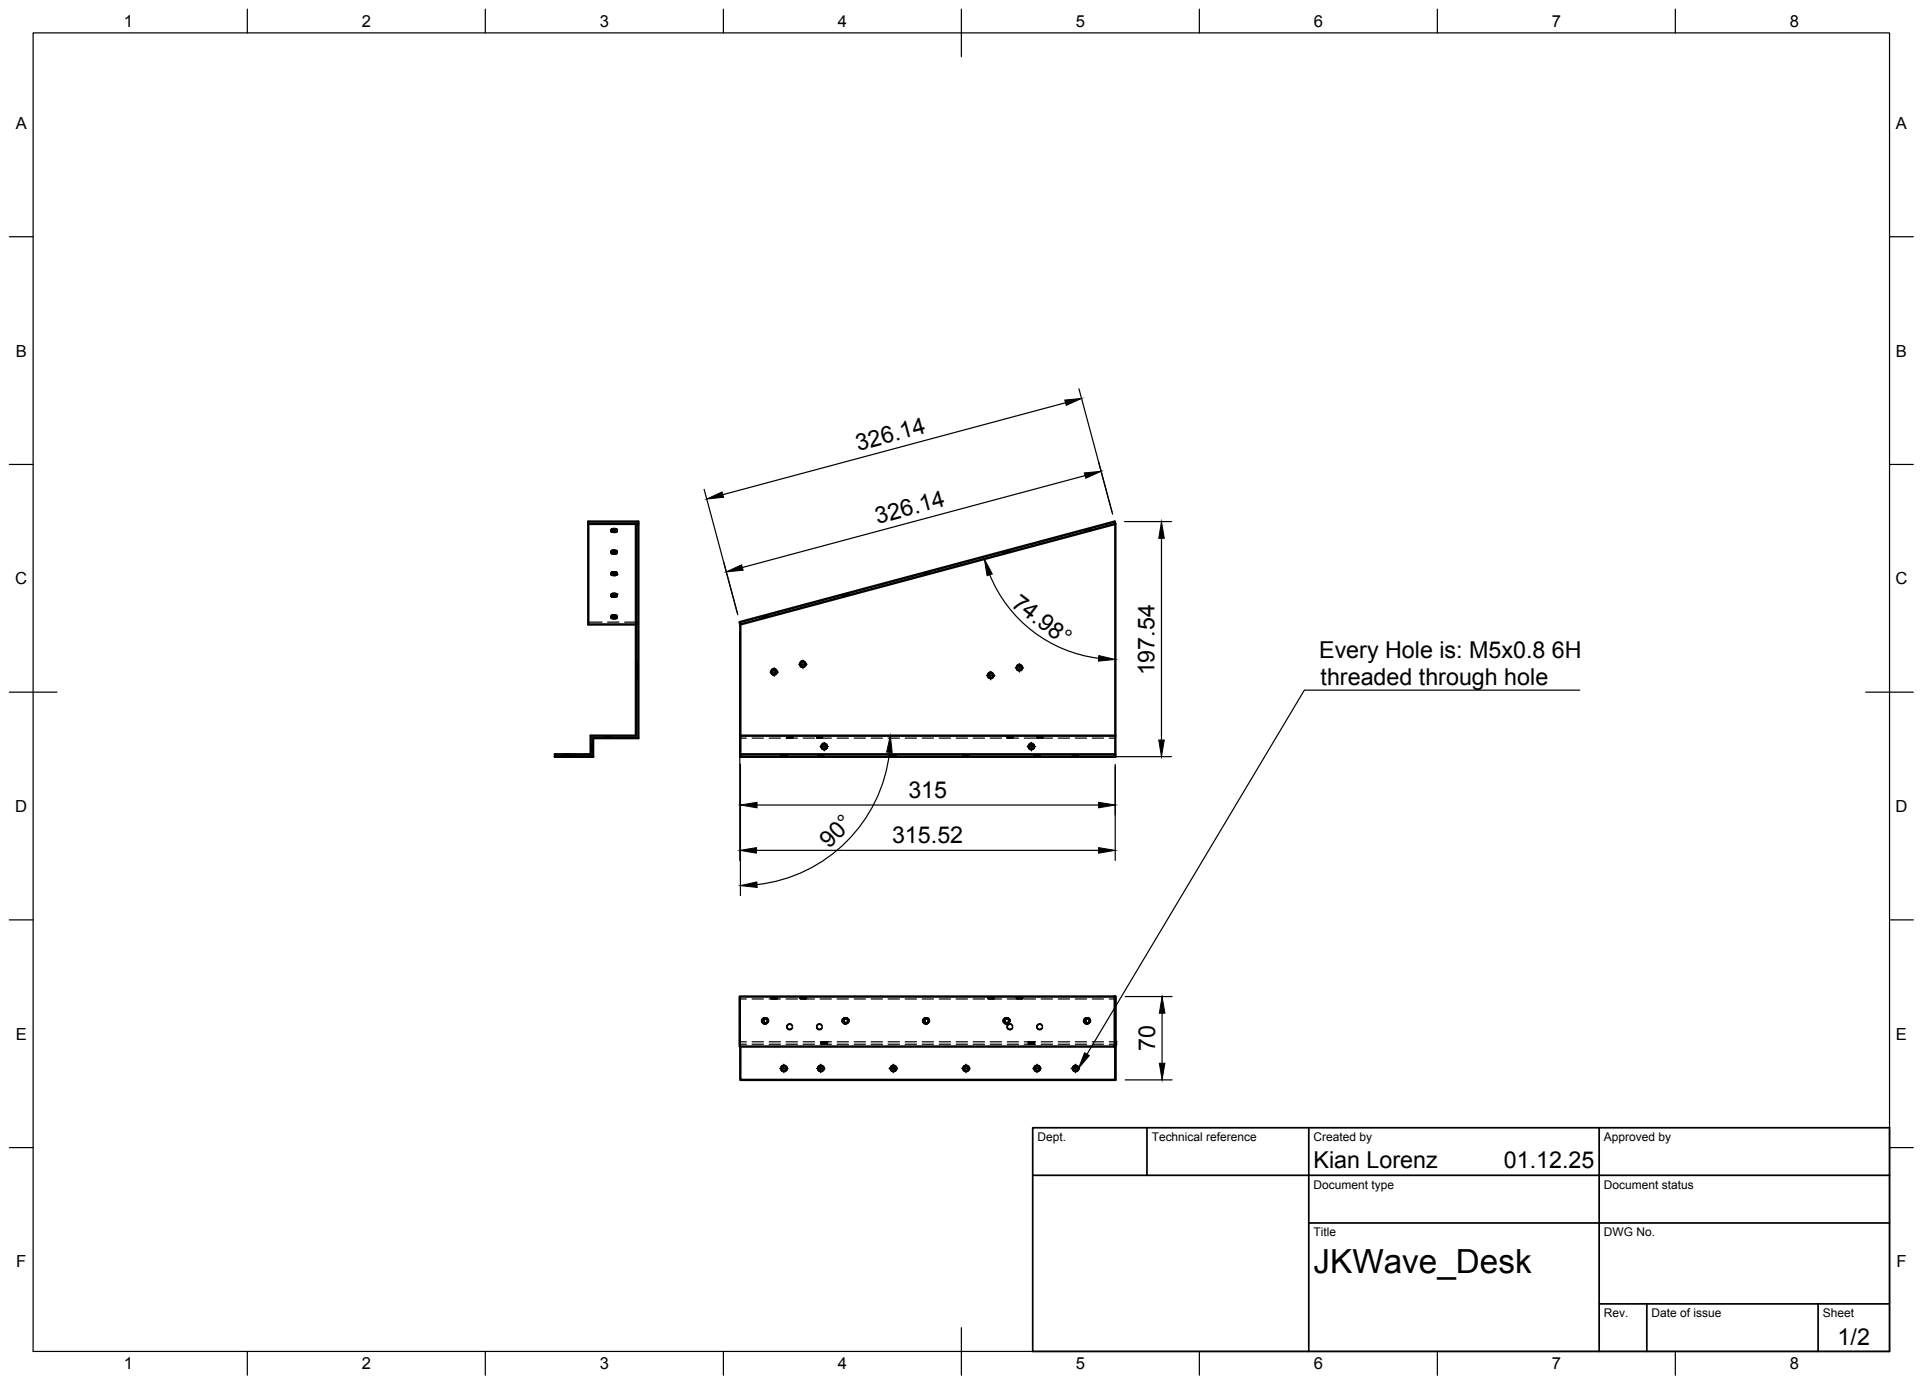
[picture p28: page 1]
Title; DWG No.; Rev.; Date of issue; Sheet

Every Hole is: M5x0.8 6H
threaded through hole

Dept. | Technical reference | Created by Kian Lorenz 01.12.25 | Approved by

Document type | Document status

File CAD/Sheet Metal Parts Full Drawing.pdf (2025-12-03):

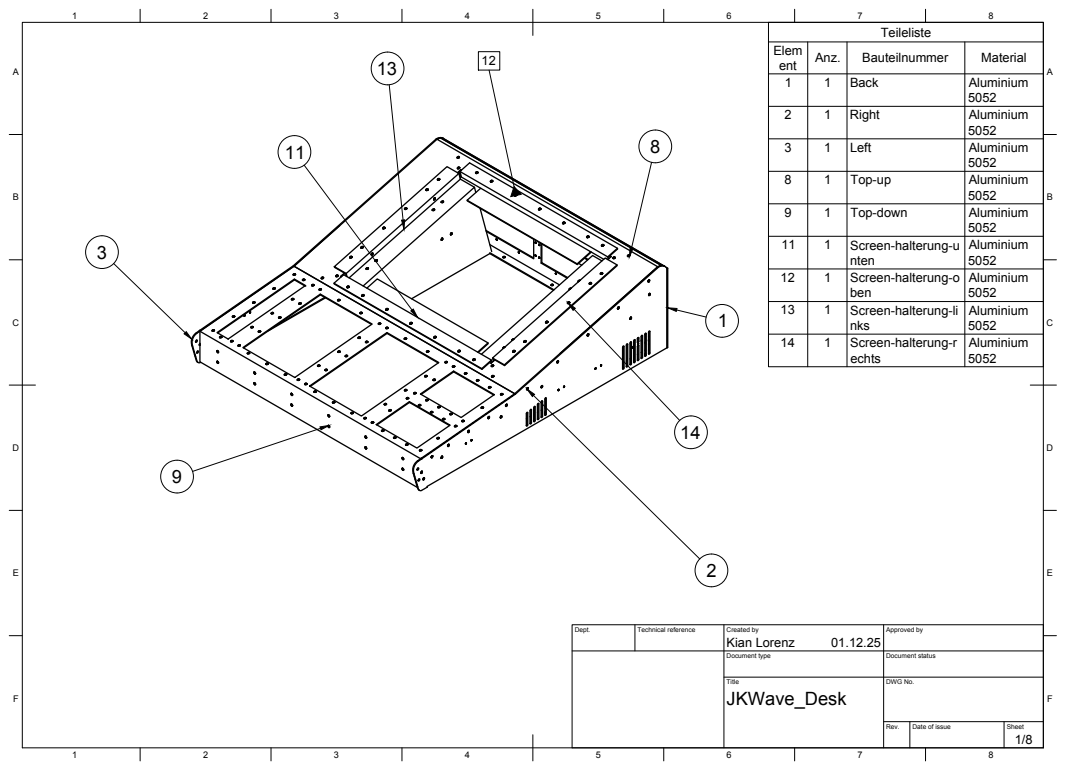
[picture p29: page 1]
8 BCDEF; ABCDEF; Title; DWG No.; Rev.; Date of issue; Sheet

Elem ent | Anz. 1 | Back Bauteilnummer | Aluminium Material 1

1 | Right | 5052 2 Aluminium

1 | Left | 5052 3 Aluminium

1 | Top-up | 5052 8 Aluminium

1 | Top-down | 5052 9 Aluminium

11 | 1 | Screen-halterung-u nten | Aluminium 5052

12 | 1 | Screen-halterung-o ben | Aluminium 5052

13 | 1 | Screen-halterung-li nks | Aluminium 5052

14 | 1 | Screen-halterung-r echts | Aluminium

Dept. | Technical reference | Created by Kian Lorenz 01.12.25 | Approved by

Document type | Document status

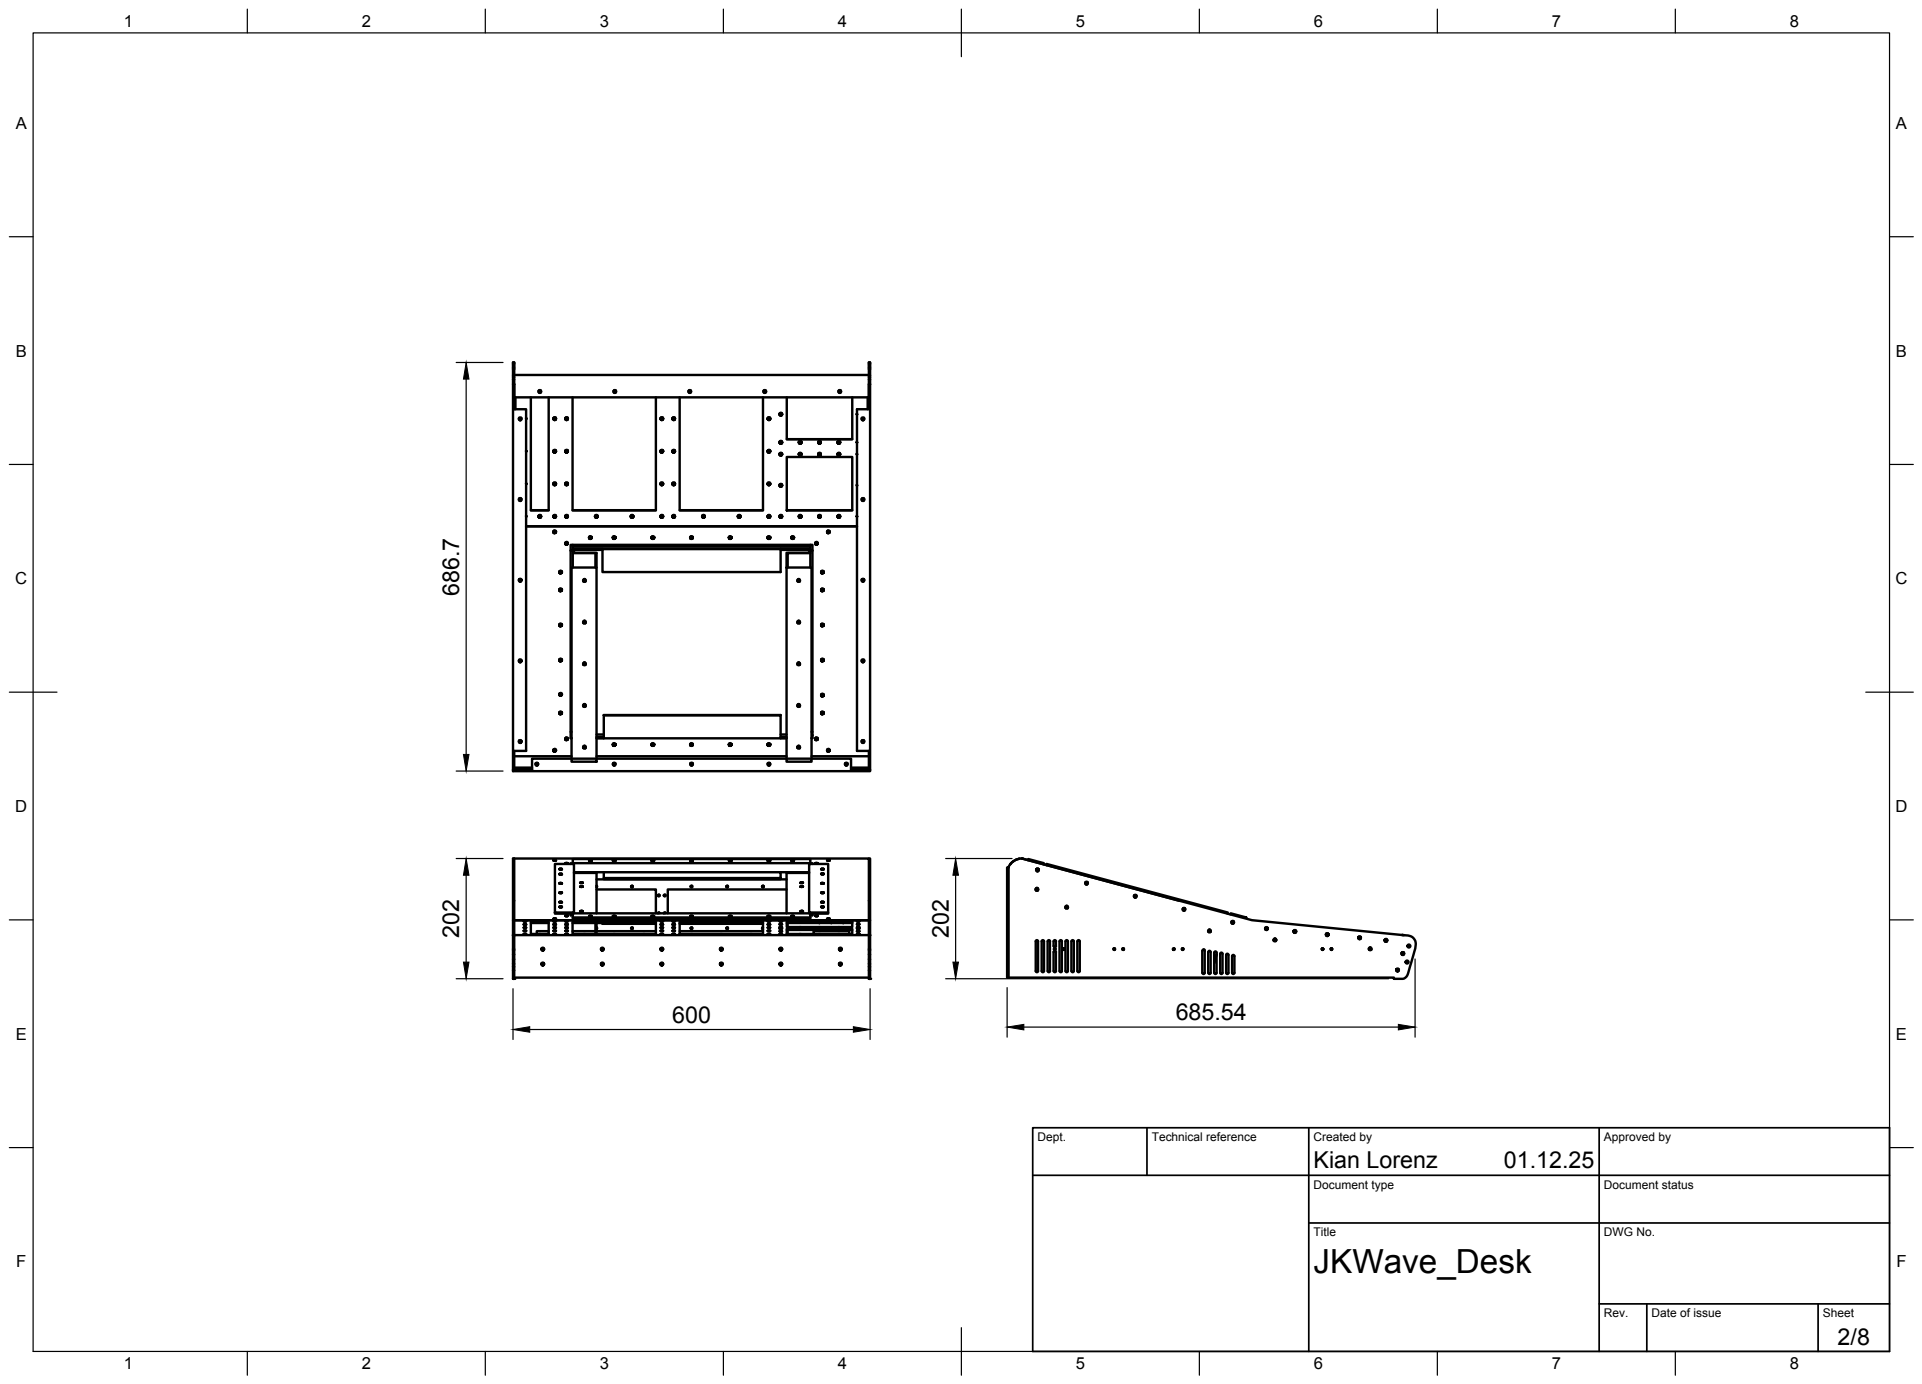
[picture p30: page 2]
Title; DWG No.; Rev.; Date of issue; Sheet

Dept. | Technical reference | Created by Kian Lorenz 01.12.25 | Approved by

Document type | Document status

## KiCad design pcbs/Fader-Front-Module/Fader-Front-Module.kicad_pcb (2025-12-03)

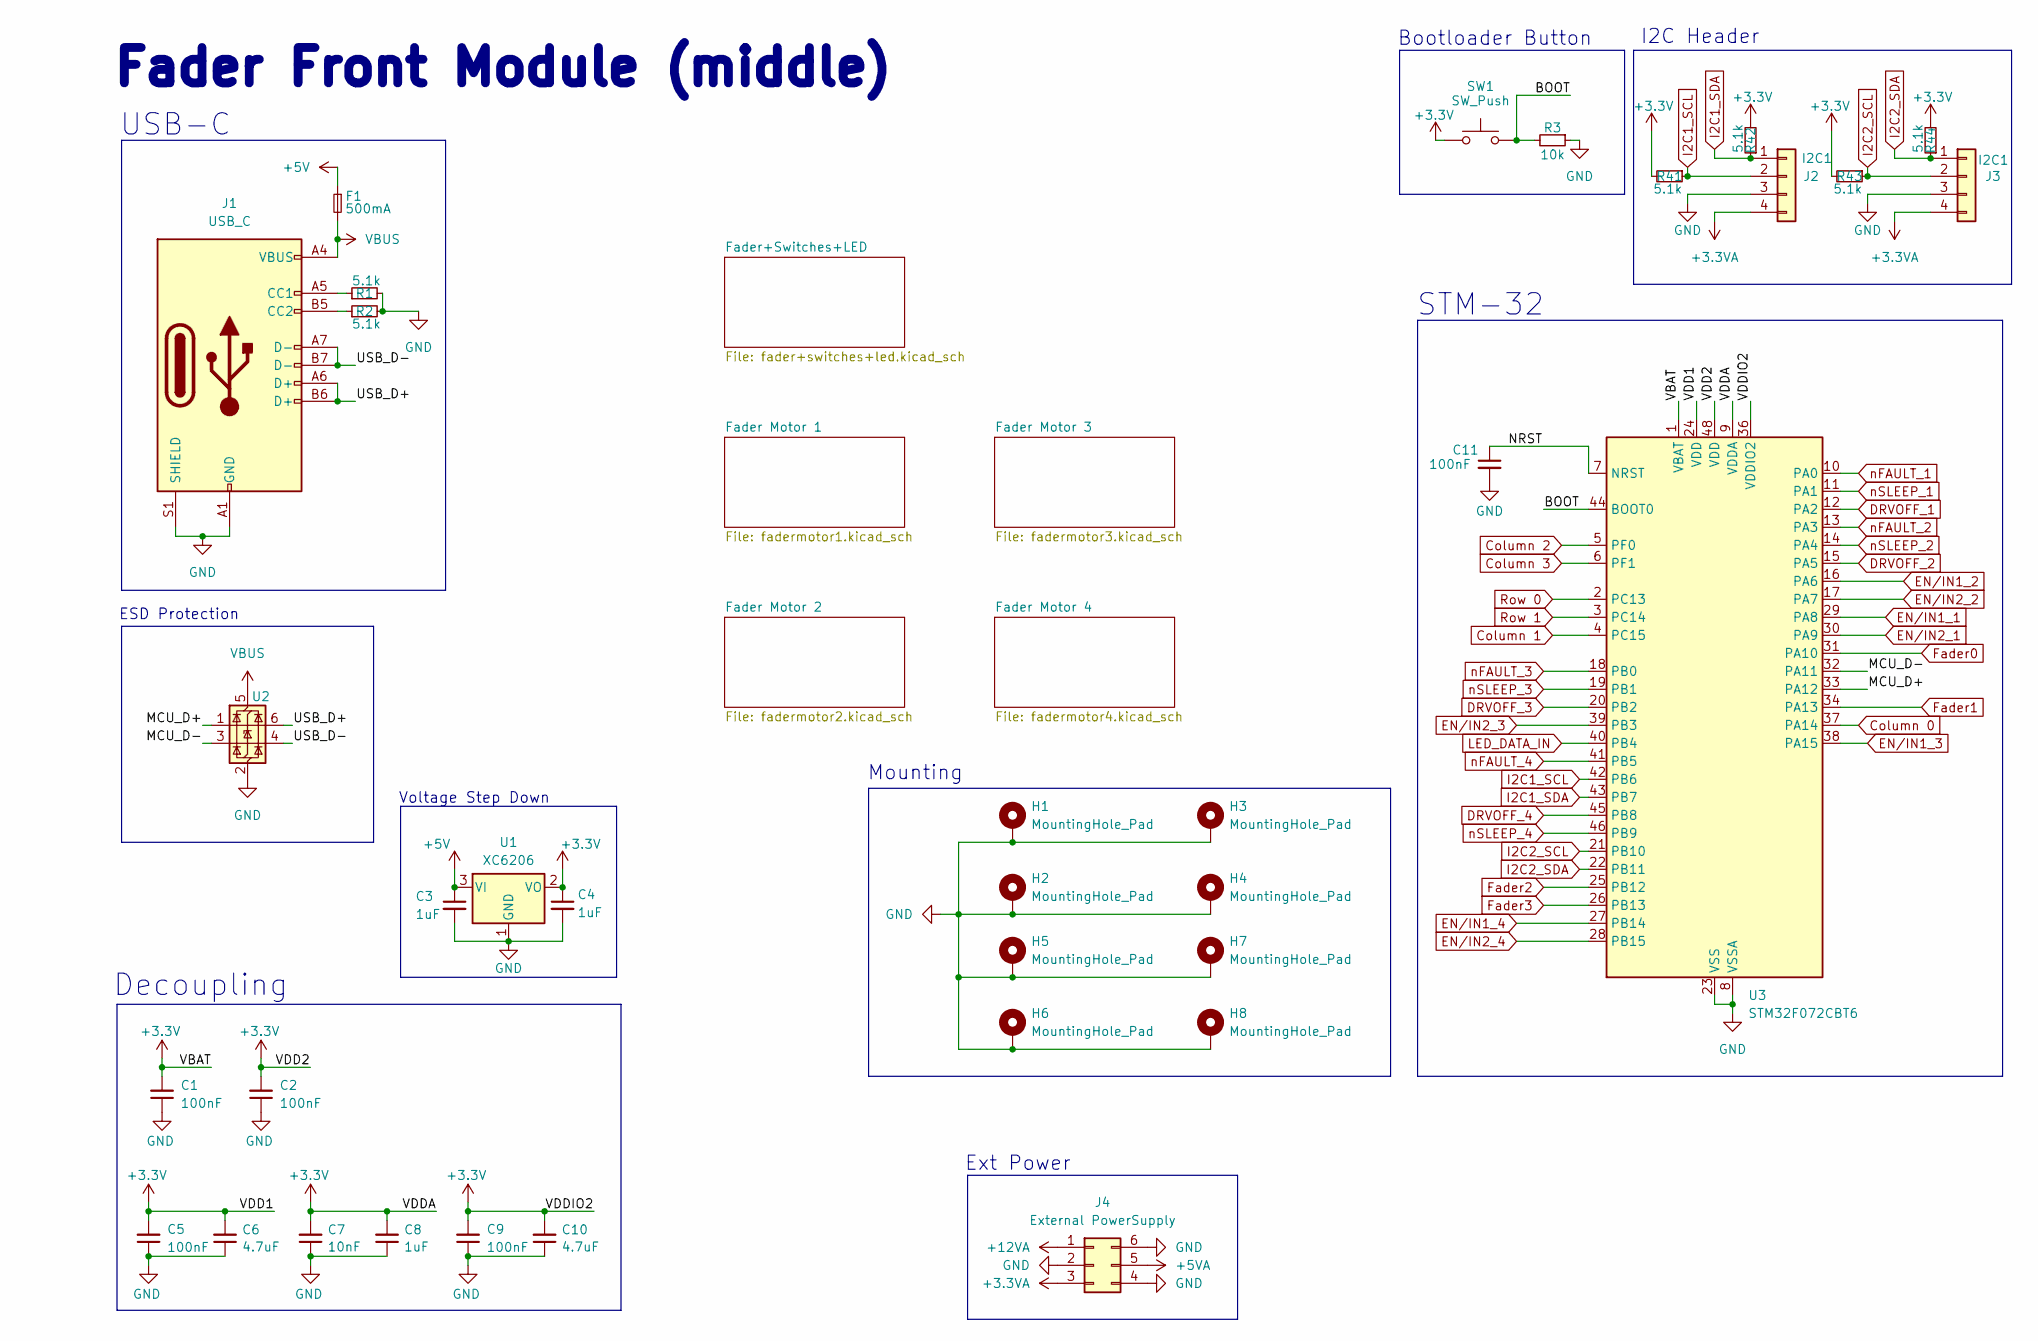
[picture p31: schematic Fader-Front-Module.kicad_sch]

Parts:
C1, C11: 100nF; C_0402_1005Metric_Pad0.74x0.62mm_HandSolder; LCSC C307331
C2, C5, C9: 100nF; C_0402_1005Metric_Pad0.74x0.62mm_HandSolder; MPN CL05B104KB54PNC; LCSC C307331
C3, C4: 1uF; C_0402_1005Metric_Pad0.74x0.62mm_HandSolder; LCSC C52923
C6, C10: 4.7uF; C_0402_1005Metric_Pad0.74x0.62mm_HandSolder; MPN CL05A475MP5NRNC; LCSC C23733
C7: 10nF; C_0402_1005Metric_Pad0.74x0.62mm_HandSolder; MPN CL05B103KB5NNNC; LCSC C15195
C8: 1uF; C_0402_1005Metric_Pad0.74x0.62mm_HandSolder; MPN CL05A105KA5NQNC; LCSC C52923
F1: 500mA; Fuse_0603_1608Metric_Pad1.05x0.95mm_HandSolder; LCSC C210357
H1, H2, H3, H4, H5, H6, H7, H8: MountingHole_Pad; MountingHole_2.2mm_M2_Pad_Via
J1: USB_C; USB_C_Receptacle_HRO_TYPE-C-31-M-12; LCSC C165948
J2, J3: I2C1; JST_EH_B4B-EH-A_1x04_P2.50mm_Vertical; LCSC C160258
J4: External PowerSupply; Molex_Mini-Fit_Jr_5566-06A_2x03_P4.20mm_Vertical; LCSC C471417
R1, R2, R41, R42, R43, R44: 5.1k; C_0402_1005Metric_Pad0.74x0.62mm_HandSolder; LCSC C25905
R3: 10k; C_0402_1005Metric_Pad0.74x0.62mm_HandSolder; LCSC C25744
SW1: SW_Push; SW_SPST_TL3342; LCSC C115351
U1: XC6206; SOT-23-3; LCSC C5446
U2: USBLC6-2SC6; SOT-23-6_Handsoldering; LCSC C2827654
U3: STM32F072CBT6; LQFP-48_7x7mm_P0.5mm; LCSC C81720

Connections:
+3.3V: C1.2, C2.2, C4.1, C5.2, C6.2, C7.2, C8.2, C9.2, C10.2, R41.2, R42.2, R43.2, R44.2, SW1.1, U1.2 (VO), U3.1 (VBAT), U3.9 (VDDA), U3.24 (VDD), U3.36 (VDDIO2), U3.48 (VDD)
+3.3VA: J2.4, J3.4, J4.3; also elsewhere on the board
+5V: C3.1, F1.1, U1.3 (VI)
+5VA: J4.5; also elsewhere on the board
+12VA: J4.1
/BOOT: R3.2, SW1.2, U3.44 (BOOT0)
/MCU_D+: U2.1 (I/O1), U3.33 (PA12)
/MCU_D-: U2.3 (I/O2), U3.32 (PA11)
/NRST: C11.1, U3.7 (NRST)
/USB_D+: J1.A6 (D+), J1.B6 (D+), U2.6 (I/O1)
/USB_D-: J1.A7 (D-), J1.B7 (D-), U2.4 (I/O2)
Column 0: U3.37 (PA14); also elsewhere on the board
Column 1: U3.4 (PC15); also elsewhere on the board
Column 2: U3.5 (PF0); also elsewhere on the board
Column 3: U3.6 (PF1); also elsewhere on the board
DRVOFF_1: U3.12 (PA2); also elsewhere on the board
DRVOFF_2: U3.15 (PA5); also elsewhere on the board
DRVOFF_3: U3.20 (PB2); also elsewhere on the board
DRVOFF_4: U3.45 (PB8); also elsewhere on the board
EN/IN1_1: U3.29 (PA8); also elsewhere on the board
EN/IN1_2: U3.16 (PA6); also elsewhere on the board
EN/IN1_3: U3.38 (PA15); also elsewhere on the board
EN/IN1_4: U3.27 (PB14); also elsewhere on the board
EN/IN2_1: U3.30 (PA9); also elsewhere on the board
EN/IN2_2: U3.17 (PA7); also elsewhere on the board
EN/IN2_3: U3.39 (PB3); also elsewhere on the board
EN/IN2_4: U3.28 (PB15); also elsewhere on the board
Fader0: U3.31 (PA10); also elsewhere on the board
Fader1: U3.34 (PA13); also elsewhere on the board
Fader2: U3.25 (PB12); also elsewhere on the board
Fader3: U3.26 (PB13); also elsewhere on the board
GND: C1.1, C2.1, C3.2, C4.2, C5.1, C6.1, C7.1, C8.1, C9.1, C10.1, C11.2, H1.1, H2.1, H3.1, H4.1, H5.1, H6.1, H7.1, H8.1, J1.A1 (GND), J1.A12 (GND), J1.B1 (GND), J1.B12 (GND), J1.S1 (SHIELD), J2.3, J3.3, J4.2, J4.4, J4.6, R1.2, R2.2, R3.1, U1.1 (GND), U2.2 (GND), U3.8 (VSSA), U3.23 (VSS), U3.35 (VSS), U3.47 (VSS); also elsewhere on the board
I2C1_SCL: J2.2, R41.1, U3.42 (PB6)
I2C1_SDA: J2.1, R42.1, U3.43 (PB7)
I2C2_SCL: J3.2, R43.1, U3.21 (PB10)
I2C2_SDA: J3.1, R44.1, U3.22 (PB11)
LED_DATA_IN: U3.40 (PB4); also elsewhere on the board
unnamed: J1.A5 (CC1), R1.1
unnamed: J1.B5 (CC2), R2.1
Row 0: U3.2 (PC13); also elsewhere on the board
Row 1: U3.3 (PC14); also elsewhere on the board
VBUS: F1.2, J1.A4 (VBUS), J1.A9 (VBUS), J1.B4 (VBUS), J1.B9 (VBUS), U2.5 (VBUS)
nFAULT_1: U3.10 (PA0); also elsewhere on the board
nFAULT_2: U3.13 (PA3); also elsewhere on the board
nFAULT_3: U3.18 (PB0); also elsewhere on the board
nFAULT_4: U3.41 (PB5); also elsewhere on the board
nSLEEP_1: U3.11 (PA1); also elsewhere on the board
nSLEEP_2: U3.14 (PA4); also elsewhere on the board
nSLEEP_3: U3.19 (PB1); also elsewhere on the board
nSLEEP_4: U3.46 (PB9); also elsewhere on the board

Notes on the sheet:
Ext Power
ESD Protection
Mounting
I2C Header
Voltage Step Down
Bootloader Button
Decoupling
STM-32
USB-C
Fader Front Module (middle)

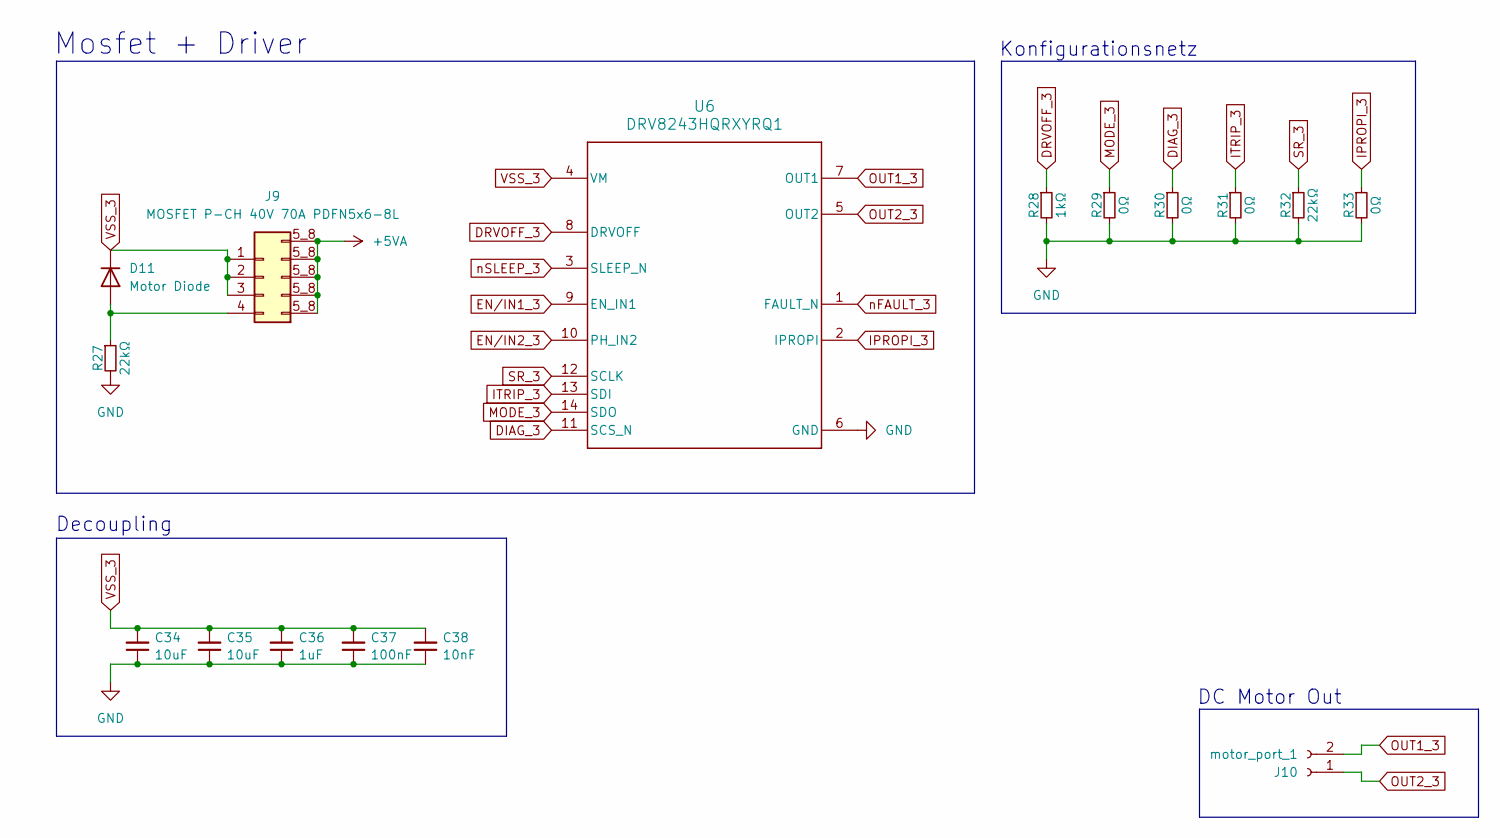
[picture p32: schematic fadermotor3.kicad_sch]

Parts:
C34, C35: 10uF; C_0805_2012Metric_Pad1.18x1.45mm_HandSolder; LCSC C15850
C36: 1uF; C_0805_2012Metric_Pad1.18x1.45mm_HandSolder; LCSC C28323
C37: 100nF; C_0805_2012Metric_Pad1.18x1.45mm_HandSolder; LCSC C49678
C38: 10nF; C_0805_2012Metric_Pad1.18x1.45mm_HandSolder; LCSC C1710
D11: Motor Diode; LL-34; LCSC C2891753
J9: MOSFET P-CH 40V 70A PDFN5x6-8L; TRANS_TSM018NB03CR_RLG; LCSC C5297498
J10: motor_port_1; SolderWire-2sqmm_1x02_P7.8mm_D2mm_OD3.9mm
R27, R32: 22kΩ; R_0805_2012Metric_Pad1.20x1.40mm_HandSolder; LCSC C2907243
R28: 1kΩ; R_0805_2012Metric_Pad1.20x1.40mm_HandSolder; LCSC C95781
R29, R30, R31, R33: 0Ω; R_0805_2012Metric_Pad1.20x1.40mm_HandSolder
U6: DRV8243HQRXYRQ1; RXY0014A-MFG; LCSC C3040833

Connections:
+5VA: J9.5_8 (Pin_5); also elsewhere on the board
DIAG_3: R30.1, U6.11 (SCS_N)
DRVOFF_3: R28.1, U6.8 (DRVOFF); also elsewhere on the board
EN/IN1_3: U6.9 (EN_IN1); also elsewhere on the board
EN/IN2_3: U6.10 (PH_IN2); also elsewhere on the board
GND: C34.1, C35.1, C36.1, C37.1, C38.1, R27.2, R28.2, R29.2, R30.2, R31.2, R32.2, R33.2, U6.6 (GND); also elsewhere on the board
IPROPI_3: R33.1, U6.2 (IPROPI)
ITRIP_3: R31.1, U6.13 (SDI)
MODE_3: R29.1, U6.14 (SDO)
unnamed: D11.2 (A), J9.4, R27.1
OUT1_3: J10.2, U6.7 (OUT1)
OUT2_3: J10.1, U6.5 (OUT2)
SR_3: R32.1, U6.12 (SCLK)
VSS_3: C34.2, C35.2, C36.2, C37.2, C38.2, D11.1 (K), J9.1, J9.2, J9.3, U6.4 (VM)
nFAULT_3: U6.1 (FAULT_N); also elsewhere on the board
nSLEEP_3: U6.3 (SLEEP_N); also elsewhere on the board

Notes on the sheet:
Mosfet + Driver
Decoupling
DC Motor Out
Konfigurationsnetz

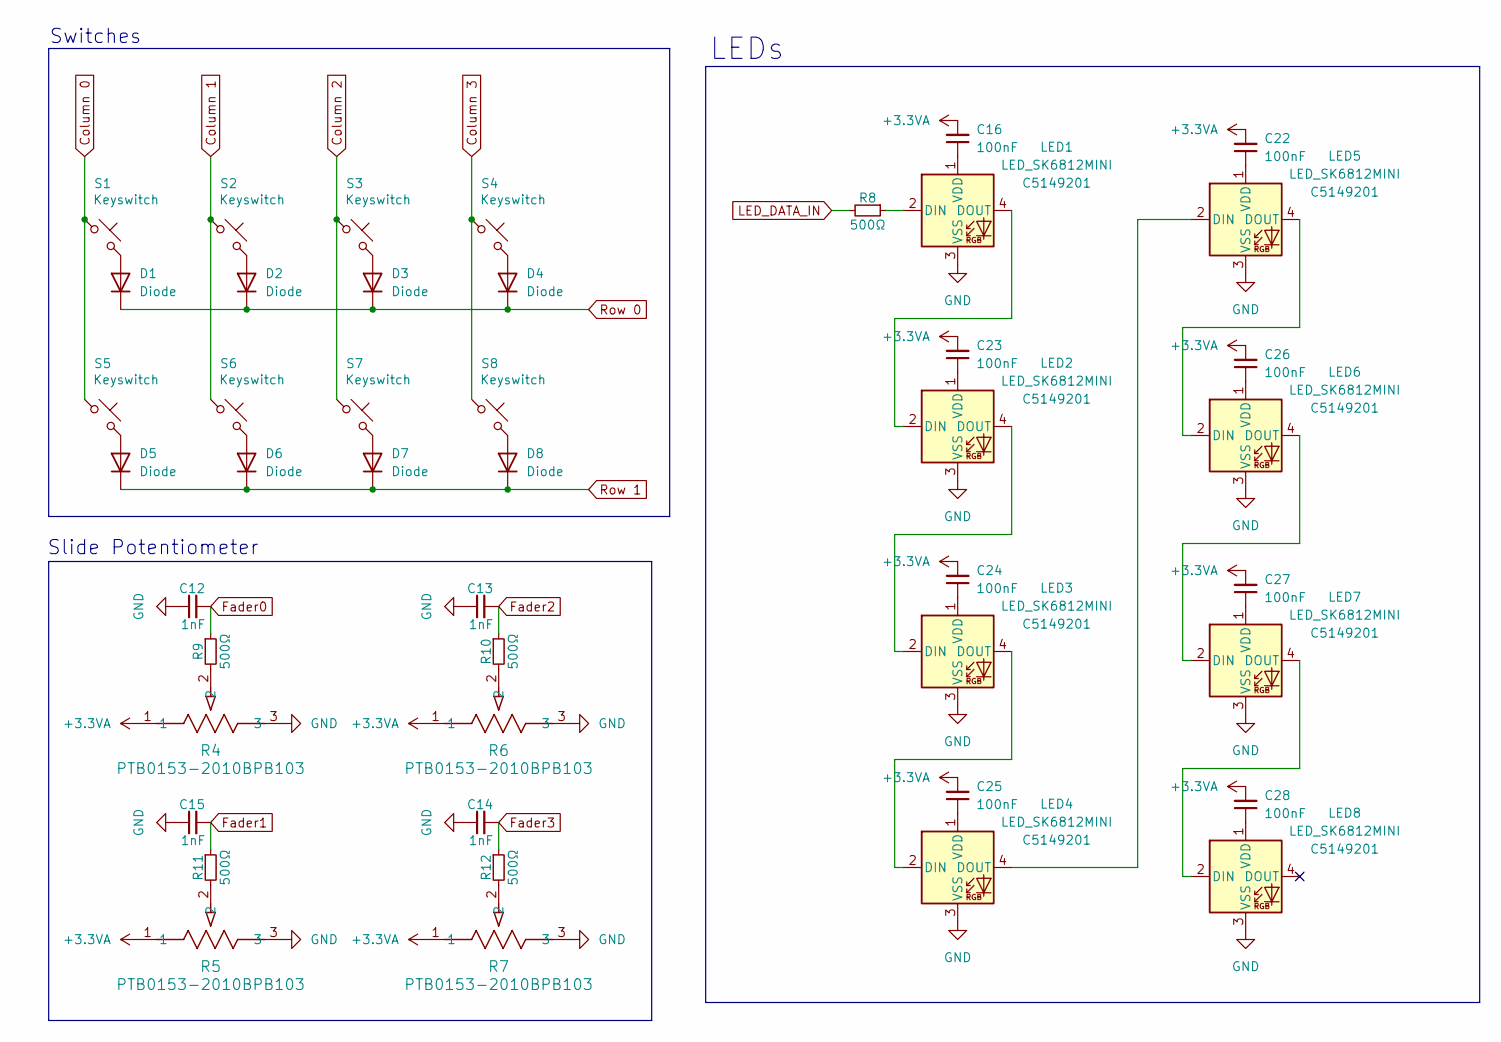
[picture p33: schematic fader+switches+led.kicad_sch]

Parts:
C12, C13, C14, C15: 1nF; C_0805_2012Metric_Pad1.18x1.45mm_HandSolder; LCSC C94121
C16, C22, C23, C24, C25, C26, C27, C28: 100nF; C_0402_1005Metric_Pad0.74x0.62mm_HandSolder; MPN CL05B104KB54PNC; LCSC C307331
D1, D2, D3, D4, D5, D6, D7, D8: Diode; SOD-123_ONS; LCSC C11177
LED1, LED2, LED3, LED4, LED5, LED6, LED7, LED8: LED_SK6812MINI; LCSC C5149201
R4, R5, R6, R7: PTB0153-2010BPB103; schieberegler-PTB0153-2010BPB103; LCSC C17427549
R8, R9, R10, R11, R12: 500Ω; R_0805_2012Metric_Pad1.20x1.40mm_HandSolder; LCSC C2828857
S1, S2, S3, S4, S5, S6, S7, S8: Keyswitch; MX_PCB_1.00u

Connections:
+3.3VA: C16.2, C22.2, C23.2, C24.2, C25.2, C26.2, C27.2, C28.2, R4.1, R5.1, R6.1, R7.1; also elsewhere on the board
Column 0: S1.1, S5.1; also elsewhere on the board
Column 1: S2.1, S6.1; also elsewhere on the board
Column 2: S3.1, S7.1; also elsewhere on the board
Column 3: S4.1, S8.1; also elsewhere on the board
Fader0: C12.2, R9.1; also elsewhere on the board
Fader1: C15.2, R11.1; also elsewhere on the board
Fader2: C13.2, R10.1; also elsewhere on the board
Fader3: C14.2, R12.1; also elsewhere on the board
GND: C12.1, C13.1, C14.1, C15.1, LED1.3 (VSS), LED2.3 (VSS), LED3.3 (VSS), LED4.3 (VSS), LED5.3 (VSS), LED6.3 (VSS), LED7.3 (VSS), LED8.3 (VSS), R4.3, R5.3, R6.3, R7.3; also elsewhere on the board
LED_DATA_IN: R8.2; also elsewhere on the board
unnamed: D1.2 (A), S1.2
unnamed: D2.2 (A), S2.2
unnamed: D3.2 (A), S3.2
unnamed: D4.2 (A), S4.2
unnamed: D5.2 (A), S5.2
unnamed: D6.2 (A), S6.2
unnamed: D7.2 (A), S7.2
unnamed: D8.2 (A), S8.2
unnamed: LED1.2 (DIN), R8.1
unnamed: LED1.4 (DOUT), LED2.2 (DIN)
unnamed: C16.1, LED1.1 (VDD)
unnamed: LED2.4 (DOUT), LED3.2 (DIN)
unnamed: C23.1, LED2.1 (VDD)
unnamed: LED3.4 (DOUT), LED4.2 (DIN)
unnamed: C24.1, LED3.1 (VDD)
unnamed: LED4.4 (DOUT), LED5.2 (DIN)
unnamed: C25.1, LED4.1 (VDD)
unnamed: LED5.4 (DOUT), LED6.2 (DIN)
unnamed: C22.1, LED5.1 (VDD)
unnamed: LED6.4 (DOUT), LED7.2 (DIN)
unnamed: C26.1, LED6.1 (VDD)
unnamed: LED7.4 (DOUT), LED8.2 (DIN)
unnamed: C27.1, LED7.1 (VDD)
unnamed: C28.1, LED8.1 (VDD)
unnamed: R4.2, R9.2
unnamed: R6.2, R10.2
unnamed: R5.2, R11.2
unnamed: R7.2, R12.2
Row 0: D1.1 (K), D2.1 (K), D3.1 (K), D4.1 (K); also elsewhere on the board
Row 1: D5.1 (K), D6.1 (K), D7.1 (K), D8.1 (K); also elsewhere on the board

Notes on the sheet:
Switches
LEDs
Slide Potentiometer

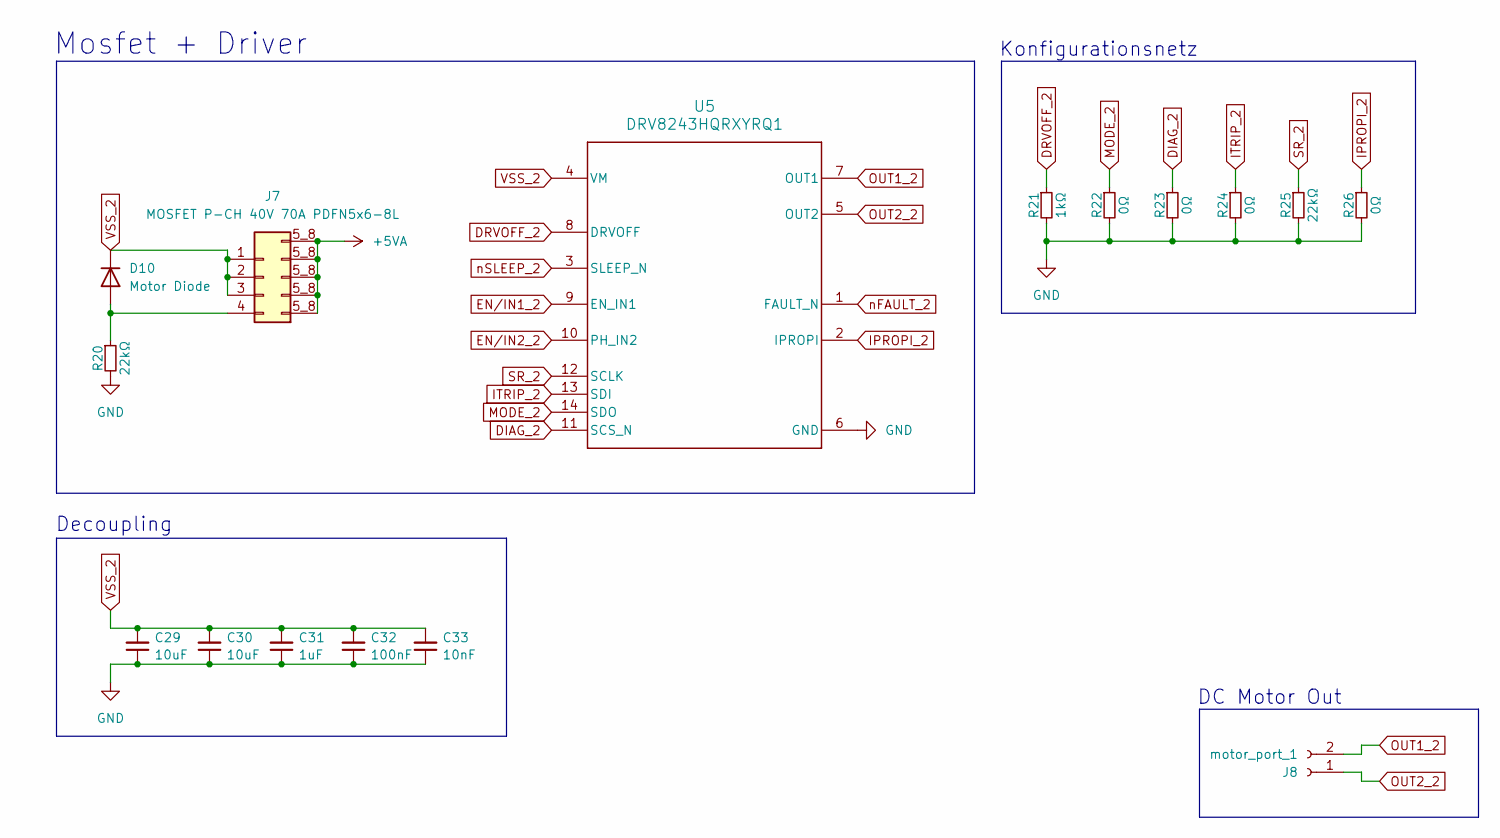
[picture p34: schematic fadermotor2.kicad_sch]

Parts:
C29, C30: 10uF; C_0805_2012Metric_Pad1.18x1.45mm_HandSolder; LCSC C15850
C31: 1uF; C_0805_2012Metric_Pad1.18x1.45mm_HandSolder; LCSC C28323
C32: 100nF; C_0805_2012Metric_Pad1.18x1.45mm_HandSolder; LCSC C49678
C33: 10nF; C_0805_2012Metric_Pad1.18x1.45mm_HandSolder; LCSC C1710
D10: Motor Diode; LL-34; LCSC C2891753
J7: MOSFET P-CH 40V 70A PDFN5x6-8L; TRANS_TSM018NB03CR_RLG; LCSC C5297498
J8: motor_port_1; SolderWire-2sqmm_1x02_P7.8mm_D2mm_OD3.9mm
R20, R25: 22kΩ; R_0805_2012Metric_Pad1.20x1.40mm_HandSolder; LCSC C2907243
R21: 1kΩ; R_0805_2012Metric_Pad1.20x1.40mm_HandSolder; LCSC C95781
R22, R23, R24, R26: 0Ω; R_0805_2012Metric_Pad1.20x1.40mm_HandSolder
U5: DRV8243HQRXYRQ1; RXY0014A-MFG; LCSC C3040833

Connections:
+5VA: J7.5_8 (Pin_8); also elsewhere on the board
DIAG_2: R23.1, U5.11 (SCS_N)
DRVOFF_2: R21.1, U5.8 (DRVOFF); also elsewhere on the board
EN/IN1_2: U5.9 (EN_IN1); also elsewhere on the board
EN/IN2_2: U5.10 (PH_IN2); also elsewhere on the board
GND: C29.1, C30.1, C31.1, C32.1, C33.1, R20.2, R21.2, R22.2, R23.2, R24.2, R25.2, R26.2, U5.6 (GND); also elsewhere on the board
IPROPI_2: R26.1, U5.2 (IPROPI)
ITRIP_2: R24.1, U5.13 (SDI)
MODE_2: R22.1, U5.14 (SDO)
unnamed: D10.2 (A), J7.4, R20.1
OUT1_2: J8.2, U5.7 (OUT1)
OUT2_2: J8.1, U5.5 (OUT2)
SR_2: R25.1, U5.12 (SCLK)
VSS_2: C29.2, C30.2, C31.2, C32.2, C33.2, D10.1 (K), J7.1, J7.2, J7.3, U5.4 (VM)
nFAULT_2: U5.1 (FAULT_N); also elsewhere on the board
nSLEEP_2: U5.3 (SLEEP_N); also elsewhere on the board

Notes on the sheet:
Konfigurationsnetz
Mosfet + Driver
DC Motor Out
Decoupling

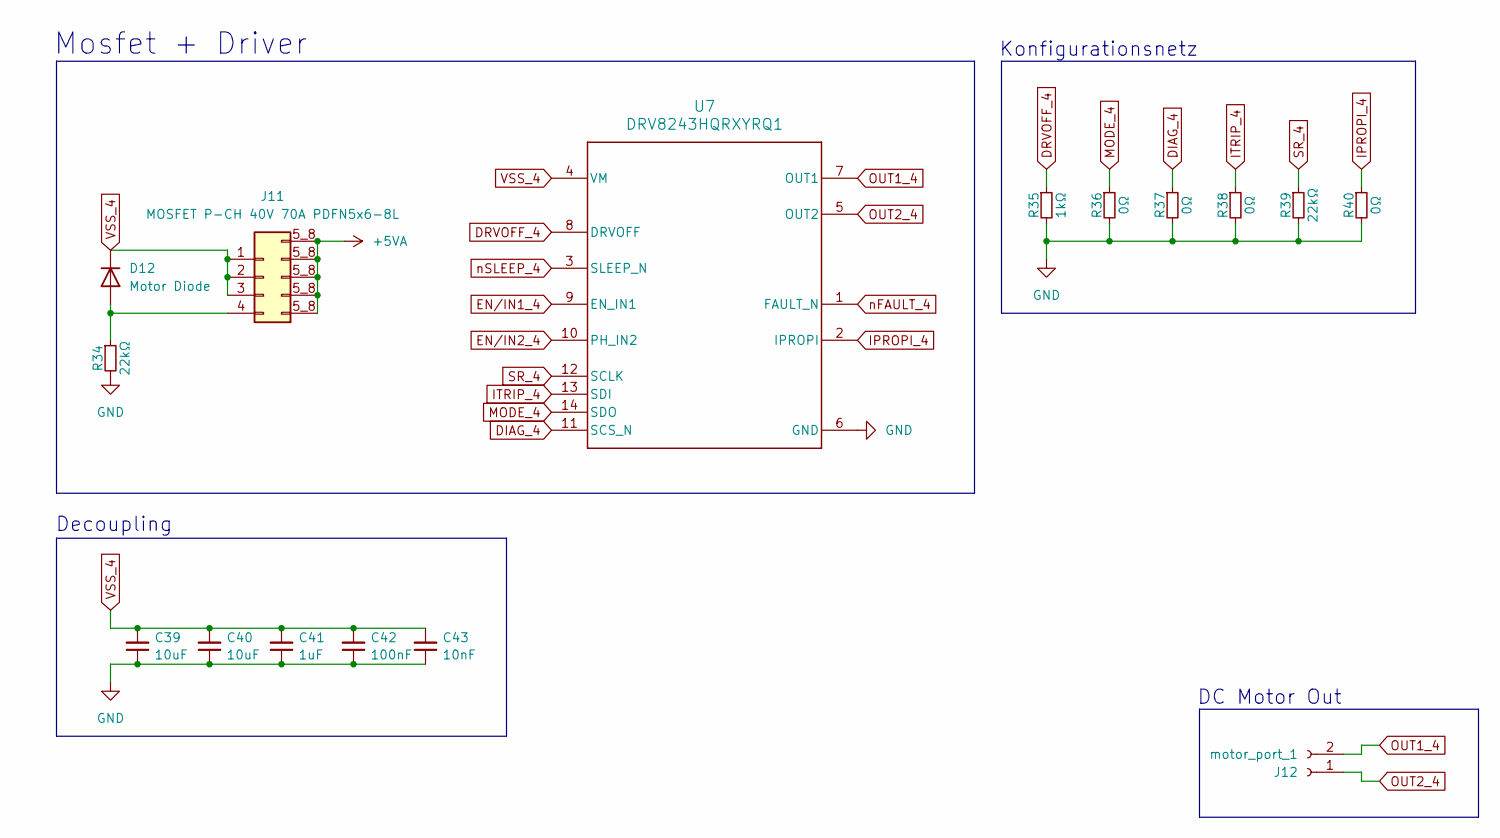
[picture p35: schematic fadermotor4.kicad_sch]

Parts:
C39, C40: 10uF; C_0805_2012Metric_Pad1.18x1.45mm_HandSolder; LCSC C15850
C41: 1uF; C_0805_2012Metric_Pad1.18x1.45mm_HandSolder; LCSC C28323
C42: 100nF; C_0805_2012Metric_Pad1.18x1.45mm_HandSolder; LCSC C49678
C43: 10nF; C_0805_2012Metric_Pad1.18x1.45mm_HandSolder; LCSC C1710
D12: Motor Diode; LL-34; LCSC C2891753
J11: MOSFET P-CH 40V 70A PDFN5x6-8L; TRANS_TSM018NB03CR_RLG; LCSC C5297498
J12: motor_port_1; SolderWire-2sqmm_1x02_P7.8mm_D2mm_OD3.9mm
R34, R39: 22kΩ; R_0805_2012Metric_Pad1.20x1.40mm_HandSolder; LCSC C2907243
R35: 1kΩ; R_0805_2012Metric_Pad1.20x1.40mm_HandSolder; LCSC C95781
R36, R37, R38, R40: 0Ω; R_0805_2012Metric_Pad1.20x1.40mm_HandSolder
U7: DRV8243HQRXYRQ1; RXY0014A-MFG; LCSC C3040833

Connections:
+5VA: J11.5_8 (Pin_9); also elsewhere on the board
DIAG_4: R37.1, U7.11 (SCS_N)
DRVOFF_4: R35.1, U7.8 (DRVOFF); also elsewhere on the board
EN/IN1_4: U7.9 (EN_IN1); also elsewhere on the board
EN/IN2_4: U7.10 (PH_IN2); also elsewhere on the board
GND: C39.1, C40.1, C41.1, C42.1, C43.1, R34.2, R35.2, R36.2, R37.2, R38.2, R39.2, R40.2, U7.6 (GND); also elsewhere on the board
IPROPI_4: R40.1, U7.2 (IPROPI)
ITRIP_4: R38.1, U7.13 (SDI)
MODE_4: R36.1, U7.14 (SDO)
unnamed: D12.2 (A), J11.4, R34.1
OUT1_4: J12.2, U7.7 (OUT1)
OUT2_4: J12.1, U7.5 (OUT2)
SR_4: R39.1, U7.12 (SCLK)
VSS_4: C39.2, C40.2, C41.2, C42.2, C43.2, D12.1 (K), J11.1, J11.2, J11.3, U7.4 (VM)
nFAULT_4: U7.1 (FAULT_N); also elsewhere on the board
nSLEEP_4: U7.3 (SLEEP_N); also elsewhere on the board

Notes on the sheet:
Mosfet + Driver
Konfigurationsnetz
DC Motor Out
Decoupling

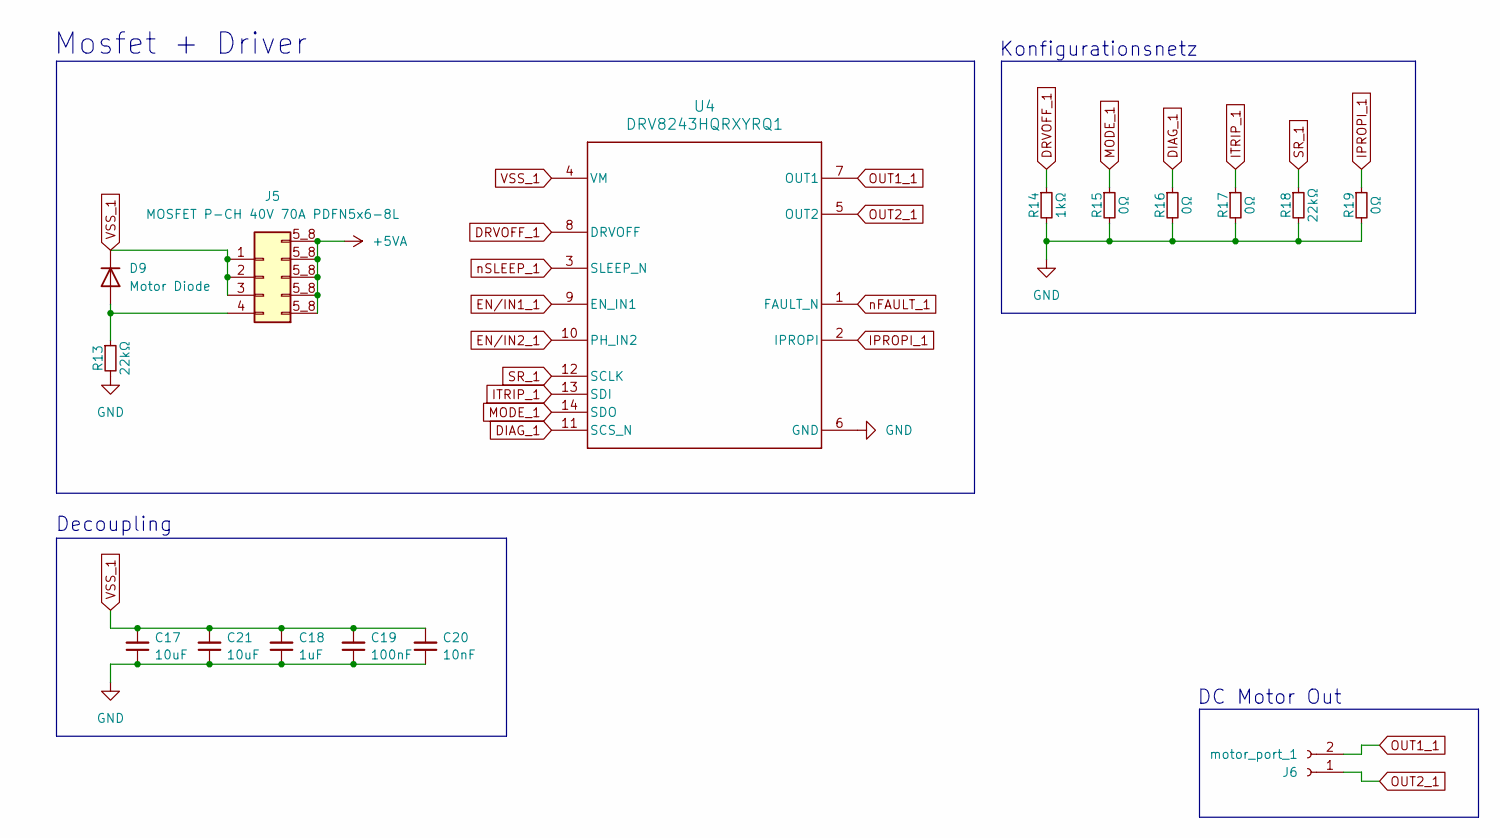
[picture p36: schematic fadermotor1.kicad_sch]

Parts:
C17, C21: 10uF; C_0805_2012Metric_Pad1.18x1.45mm_HandSolder; LCSC C15850
C18: 1uF; C_0805_2012Metric_Pad1.18x1.45mm_HandSolder; LCSC C28323
C19: 100nF; C_0805_2012Metric_Pad1.18x1.45mm_HandSolder; LCSC C49678
C20: 10nF; C_0805_2012Metric_Pad1.18x1.45mm_HandSolder; LCSC C1710
D9: Motor Diode; LL-34; LCSC C2891753
J5: MOSFET P-CH 40V 70A PDFN5x6-8L; TRANS_TSM018NB03CR_RLG; LCSC C5297498
J6: motor_port_1; SolderWire-2sqmm_1x02_P7.8mm_D2mm_OD3.9mm
R13, R18: 22kΩ; R_0805_2012Metric_Pad1.20x1.40mm_HandSolder; LCSC C2907243
R14: 1kΩ; R_0805_2012Metric_Pad1.20x1.40mm_HandSolder; LCSC C95781
R15, R16, R17, R19: 0Ω; R_0805_2012Metric_Pad1.20x1.40mm_HandSolder
U4: DRV8243HQRXYRQ1; RXY0014A-MFG; LCSC C3040833

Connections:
+5VA: J5.5_8 (Pin_9); also elsewhere on the board
DIAG_1: R16.1, U4.11 (SCS_N)
DRVOFF_1: R14.1, U4.8 (DRVOFF); also elsewhere on the board
EN/IN1_1: U4.9 (EN_IN1); also elsewhere on the board
EN/IN2_1: U4.10 (PH_IN2); also elsewhere on the board
GND: C17.1, C18.1, C19.1, C20.1, C21.1, R13.2, R14.2, R15.2, R16.2, R17.2, R18.2, R19.2, U4.6 (GND); also elsewhere on the board
IPROPI_1: R19.1, U4.2 (IPROPI)
ITRIP_1: R17.1, U4.13 (SDI)
MODE_1: R15.1, U4.14 (SDO)
unnamed: D9.2 (A), J5.4, R13.1
OUT1_1: J6.2, U4.7 (OUT1)
OUT2_1: J6.1, U4.5 (OUT2)
SR_1: R18.1, U4.12 (SCLK)
VSS_1: C17.2, C18.2, C19.2, C20.2, C21.2, D9.1 (K), J5.1, J5.2, J5.3, U4.4 (VM)
nFAULT_1: U4.1 (FAULT_N); also elsewhere on the board
nSLEEP_1: U4.3 (SLEEP_N); also elsewhere on the board

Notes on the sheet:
Konfigurationsnetz
Mosfet + Driver
DC Motor Out
Decoupling

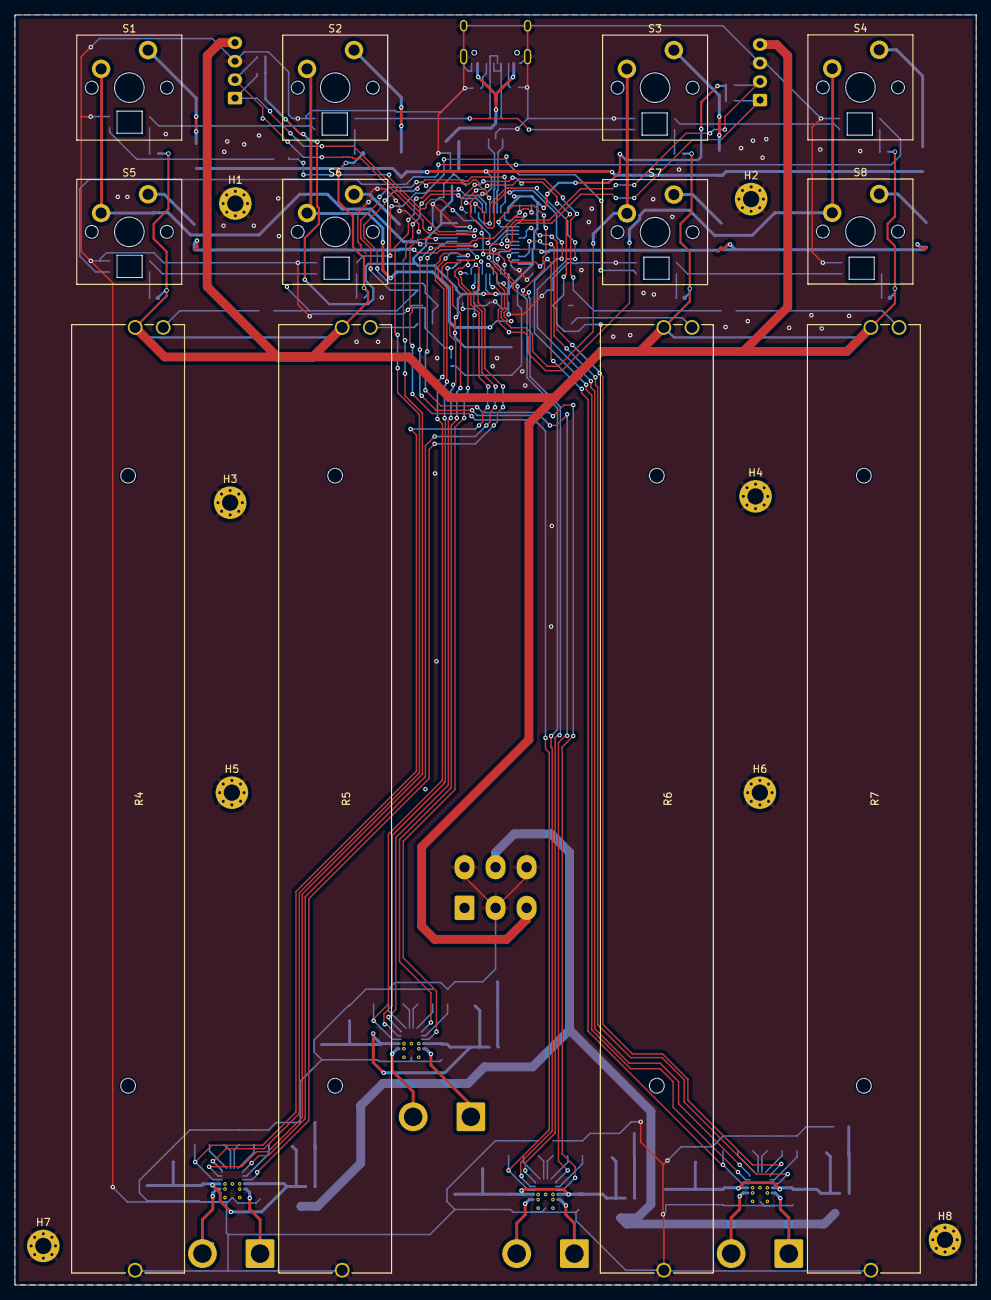
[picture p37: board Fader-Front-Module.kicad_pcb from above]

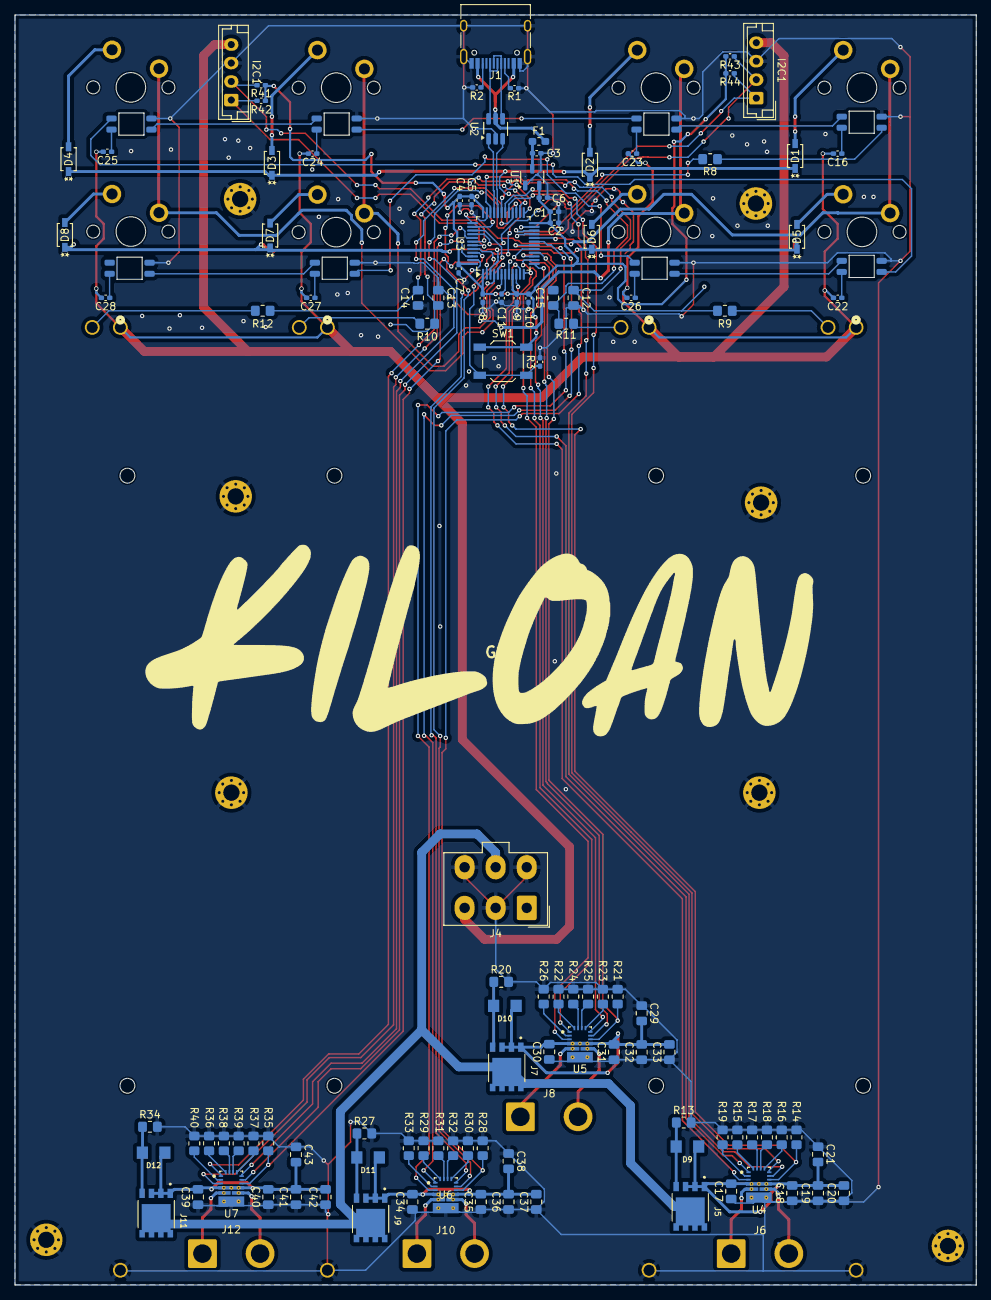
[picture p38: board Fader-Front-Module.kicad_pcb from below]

Board: 2 copper layers, 130.0 x 171.8 mm, 144 parts (124 on the bottom side), 113 nets.

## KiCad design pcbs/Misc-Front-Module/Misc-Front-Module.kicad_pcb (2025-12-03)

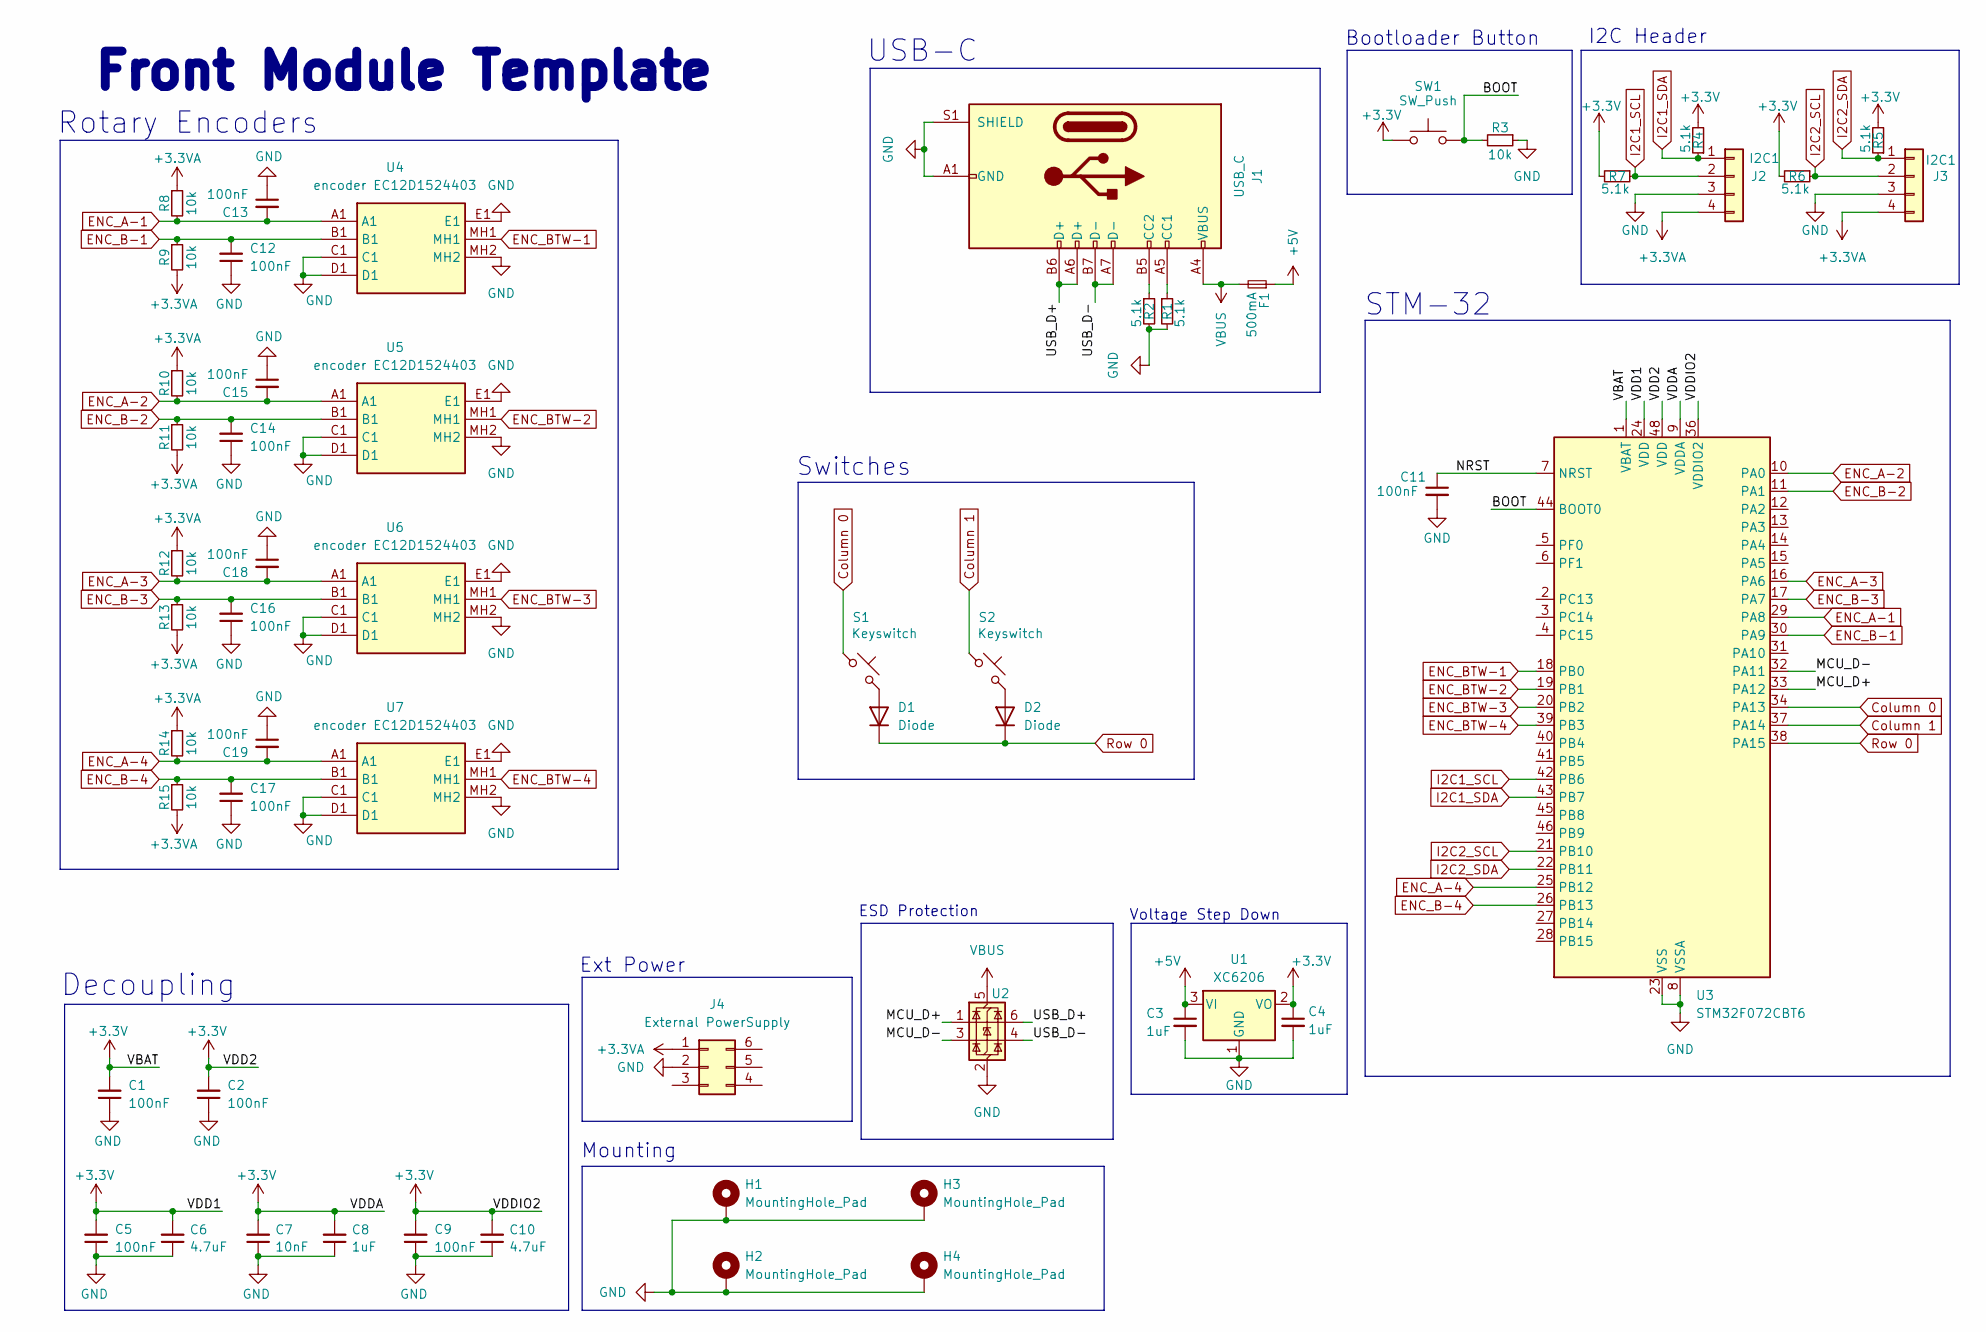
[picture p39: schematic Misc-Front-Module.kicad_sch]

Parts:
C1, C11: 100nF; C_0402_1005Metric_Pad0.74x0.62mm_HandSolder; LCSC C307331
C2, C5, C9, C12, C13, C14, C15, C16, C17, C18, C19: 100nF; C_0402_1005Metric_Pad0.74x0.62mm_HandSolder; MPN CL05B104KB54PNC; LCSC C307331
C3, C4: 1uF; C_0402_1005Metric_Pad0.74x0.62mm_HandSolder; LCSC C52923
C6, C10: 4.7uF; C_0402_1005Metric_Pad0.74x0.62mm_HandSolder; MPN CL05A475MP5NRNC; LCSC C23733
C7: 10nF; C_0402_1005Metric_Pad0.74x0.62mm_HandSolder; MPN CL05B103KB5NNNC; LCSC C15195
C8: 1uF; C_0402_1005Metric_Pad0.74x0.62mm_HandSolder; MPN CL05A105KA5NQNC; LCSC C52923
D1, D2: Diode; SOD-123_ONS; LCSC C11177
F1: 500mA; Fuse_0603_1608Metric_Pad1.05x0.95mm_HandSolder; LCSC C210357
H1, H2, H3, H4: MountingHole_Pad; MountingHole_2.2mm_M2_Pad_Via
J1: USB_C; USB_C_Receptacle_HRO_TYPE-C-31-M-12; LCSC C165948
J2, J3: I2C1; JST_EH_B4B-EH-A_1x04_P2.50mm_Vertical; LCSC C160258
J4: External PowerSupply; SolderWire-2sqmm_1x02_P7.8mm_D2mm_OD3.9mm; LCSC C471417
R1, R2, R4, R5, R6, R7: 5.1k; C_0402_1005Metric_Pad0.74x0.62mm_HandSolder; LCSC C25905
R3, R8, R9, R10, R11, R12, R13, R14, R15: 10k; C_0402_1005Metric_Pad0.74x0.62mm_HandSolder; LCSC C25744
S1, S2: Keyswitch; MX_PCB_1.00u
SW1: SW_Push; SW_SPST_TL3342; LCSC C115351
U1: XC6206; SOT-23-3; LCSC C5446
U2: USBLC6-2SC6; SOT-23-6_Handsoldering; LCSC C2827654
U3: STM32F072CBT6; LQFP-48_7x7mm_P0.5mm; LCSC C81720
U4, U5, U6, U7: encoder EC12D1524403; EC12D1524403; LCSC C112349

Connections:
+3.3V: C1.2, C2.2, C4.1, C5.2, C6.2, C7.2, C8.2, C9.2, C10.2, R4.2, R5.2, R6.2, R7.2, SW1.1, U1.2 (VO), U3.1 (VBAT), U3.9 (VDDA), U3.24 (VDD), U3.36 (VDDIO2), U3.48 (VDD)
+3.3VA: J2.4, J3.4, J4.1, R8.1, R9.2, R10.1, R11.2, R12.1, R13.2, R14.1, R15.2
+5V: C3.1, F1.1, U1.3 (VI)
/BOOT: R3.2, SW1.2, U3.44 (BOOT0)
/MCU_D+: U2.1 (I/O1), U3.33 (PA12)
/MCU_D-: U2.3 (I/O2), U3.32 (PA11)
/NRST: C11.1, U3.7 (NRST)
/USB_D+: J1.A6 (D+), J1.B6 (D+), U2.6 (I/O1)
/USB_D-: J1.A7 (D-), J1.B7 (D-), U2.4 (I/O2)
Column 0: S1.1, U3.34 (PA13)
Column 1: S2.1, U3.37 (PA14)
ENC_A-1: C13.2, R8.2, U3.29 (PA8), U4.A1
ENC_A-2: C15.2, R10.2, U3.10 (PA0), U5.A1
ENC_A-3: C18.2, R12.2, U3.16 (PA6), U6.A1
ENC_A-4: C19.2, R14.2, U3.25 (PB12), U7.A1
ENC_B-1: C12.2, R9.1, U3.30 (PA9), U4.B1
ENC_B-2: C14.2, R11.1, U3.11 (PA1), U5.B1
ENC_B-3: C16.2, R13.1, U3.17 (PA7), U6.B1
ENC_B-4: C17.2, R15.1, U3.26 (PB13), U7.B1
ENC_BTW-1: U3.18 (PB0), U4.MH1
ENC_BTW-2: U3.19 (PB1), U5.MH1
ENC_BTW-3: U3.20 (PB2), U6.MH1
ENC_BTW-4: U3.39 (PB3), U7.MH1
GND: C1.1, C2.1, C3.2, C4.2, C5.1, C6.1, C7.1, C8.1, C9.1, C10.1, C11.2, C12.1, C13.1, C14.1, C15.1, C16.1, C17.1, C18.1, C19.1, H1.1, H2.1, H3.1, H4.1, J1.A1 (GND), J1.A12 (GND), J1.B1 (GND), J1.B12 (GND), J1.S1 (SHIELD), J2.3, J3.3, J4.2, R1.2, R2.2, R3.1, U1.1 (GND), U2.2 (GND), U3.8 (VSSA), U3.23 (VSS), U3.35 (VSS), U3.47 (VSS), U4.C1, U4.D1, U4.E1, U4.MH2, U5.C1, U5.D1, U5.E1, U5.MH2, U6.C1, U6.D1, U6.E1, U6.MH2, U7.C1, U7.D1, U7.E1, U7.MH2
I2C1_SCL: J2.2, R7.1, U3.42 (PB6)
I2C1_SDA: J2.1, R4.1, U3.43 (PB7)
I2C2_SCL: J3.2, R6.1, U3.21 (PB10)
I2C2_SDA: J3.1, R5.1, U3.22 (PB11)
unnamed: D1.2 (A), S1.2
unnamed: D2.2 (A), S2.2
unnamed: J1.A5 (CC1), R1.1
unnamed: J1.B5 (CC2), R2.1
Row 0: D1.1 (K), D2.1 (K), U3.38 (PA15)
VBUS: F1.2, J1.A4 (VBUS), J1.A9 (VBUS), J1.B4 (VBUS), J1.B9 (VBUS), U2.5 (VBUS)

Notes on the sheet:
ESD Protection
I2C Header
Mounting
Ext Power
Voltage Step Down
Bootloader Button
Switches
Decoupling
STM-32
USB-C
Front Module Template
Rotary Encoders

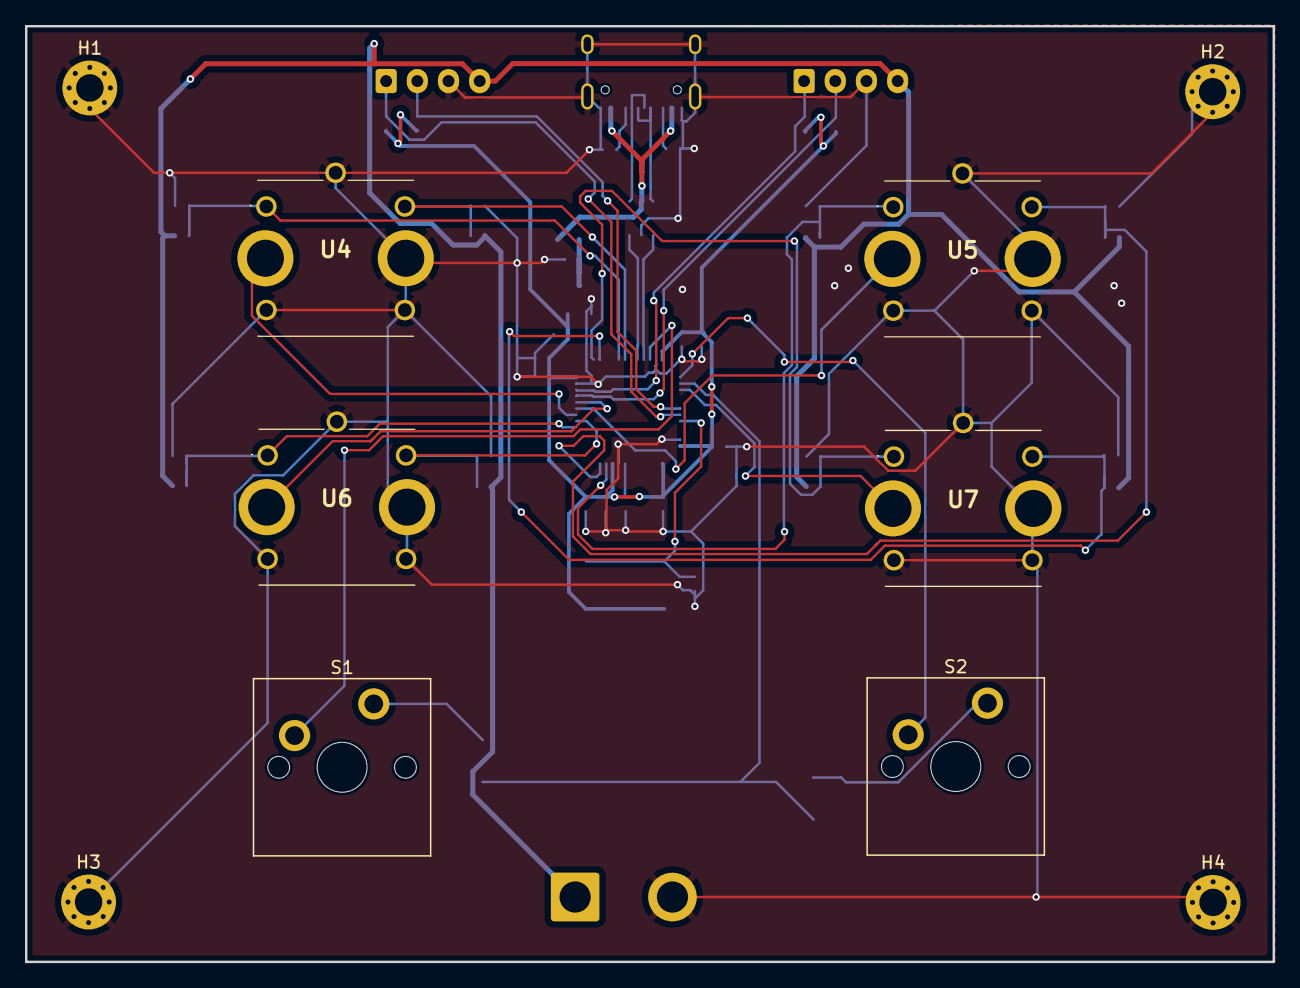
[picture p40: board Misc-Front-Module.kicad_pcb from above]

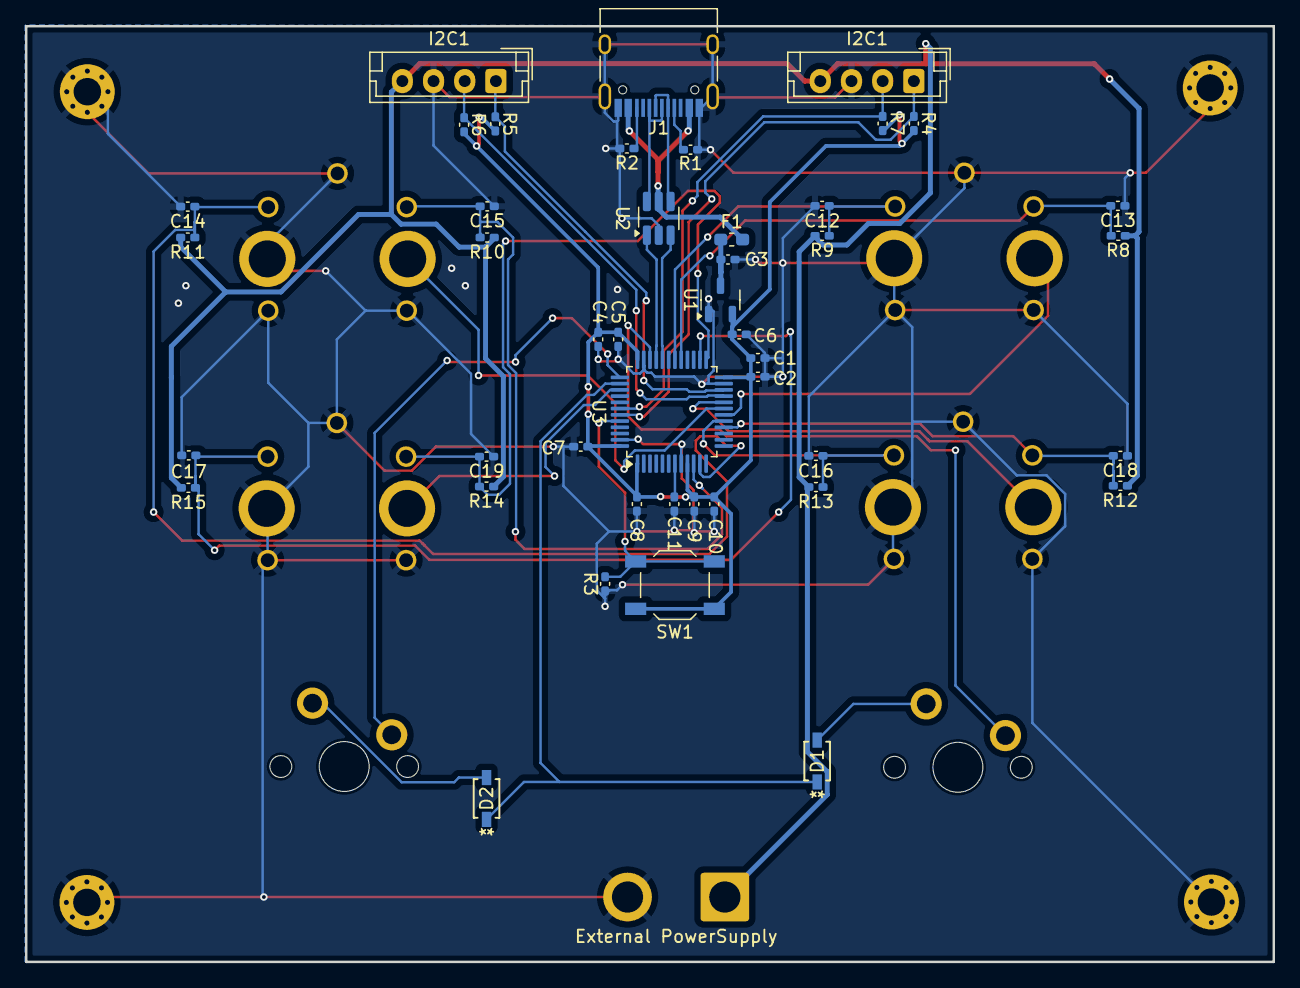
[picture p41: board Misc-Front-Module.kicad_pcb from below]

Board: 2 copper layers, 100.0 x 75.0 mm, 55 parts (44 on the bottom side), 34 nets.

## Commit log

2025-12-03 Add files
    _ Kian
    [Big-4dnorm.step, Big-6dnorm.step, Big-air.step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]
2025-12-08 modfiy left/right panel + add baseplate
    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
    [Base.step, Left.step, Right.step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]
2025-12-10 add bom
    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
    [BOM.csv, Deck-Switcher-Front-Module.kicad_pcb, Deck-Switcher-Front-Module.kicad_sch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]
2025-12-12 add estimated total and quote from jlccnc
    [BOM.csv]
2025-12-13 made bom easier to understand
    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
    [BOM.csv]
